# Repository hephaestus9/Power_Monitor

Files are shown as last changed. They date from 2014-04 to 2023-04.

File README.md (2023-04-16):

Power_Monitor
=============

Arduino and Processing sketches for Power Monitor Shield

*Boards v1r3 and v2r1 are not fully tested

This project is based on the work done by Christopher McNally.
Please view the Design_Report.pdf document for the write up of the project, and [website] (http://people.ece.cornell.edu/land/courses/eceprojectsland/STUDENTPROJ/2009to2010/csm44/index.html).

>The sample code was written for use with the 3000 Turn [CR Magnetics](http://www.crmagnetics.com/Products/CR3100-Series-P75.aspx) split core transformer. 

>If using the current transformer from [seeedstudio](http://www.seeedstudio.com/depot/Noninvasive-AC-Current-Sensor-100A-max-p-547.html?cPath=25_28) then the code needs to be changed, as this is a 2000 turn transformer.

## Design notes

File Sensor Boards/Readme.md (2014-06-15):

[Water Meter Board](http://www.instructables.com/id/Monitoring-residential-water-usage-by-reading-muni/)

[Voltage Sensor](https://courses.cit.cornell.edu/ee476/FinalProjects/s2008/cj72_xg37/cj72_xg37/index.html)

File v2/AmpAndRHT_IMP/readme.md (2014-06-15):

Electric Imp Code
=================

This code is exactly as it is running on v2r0 this is because of the Rx/Tx pins being switched on the arduino that I am using.  If you are breadboarding this then you can switch the pins to that stated in the comments of the device code.

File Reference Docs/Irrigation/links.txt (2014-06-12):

http://www.ianrpubs.unl.edu/pages/publicationD.jsp?publicationId=742
http://tlirr.com/products/pivot_management_options/
http://www.agsense.net/index.php  ~$1200 unit 200-300 monitoring fee

TDR
http://electronicdesign.com/displays/build-your-own-cable-radar

A time domain reflectometer (TDR) is a handy but rather expensive instrument, and isn�t commonly found on every bench. I used to rent them, but after having paid large bills for several years, I decided to make my own. I saved a bundle and was able to customize it for my needs.

A TDR performs a number of tasks, such as:

    sending a well-defined voltage pulse down the line and waiting for the echo.
    displaying the pulse and echo on a fast oscilloscope screen.
    measuring echo time to find cable length or distance to fault.

If you look at the list, you will find that a modern oscilloscope will do most of the job. The only thing needed for the TDR function is pulse generation. It turned out to be much easier to build than I had expected. A simple hex inverter in Advanced CMOS technology (74AC14) does the job admirably.

There are five basic design parameters that must be addressed: rise time, pulse width, amplitude, impedance, and PRF.

To be useful, the pulse should have a rise time that corresponds to the desired distance resolution. If you need 1-m resolution, then better than 10 ns is required. This design has a resolution better than 5 ns.

The pulse width can be quite short for short cables, but needs to be longer for greater length cables so that enough energy is introduced in the cable. If the energy is too low, there won�t be enough energy in the return wave to be detected reliably. This design allows a choice between 15 and 2500 ns. The 2500-ns pulse width will produce enough energy for a 5- to 10-km cable.

The other parameter that determines energy is amplitude. Too little amplitude won�t work in noisy installations. On the other hand, too much amplitude can be a problem if you�re working in installations with other cables that can pick up EMI and cause undesired responses in the system. Amplitudes between 1 and 10 V seem to serve most applications. This design uses 4 to 5 V as dictated by battery voltage.

Ordinary cables have impedances in the 50-300? range. Using a 250-? potentiometer (the low-inductance type) and a fixed generator impedance (50 ?), any impedance in that range can be achieved.

A 14-pin DIP, a handful of small components, a switch, and a potentiometer is all that�s needed. The 74AC family has quite hefty specifications. Among the features are 24-mA symmetrical sink/source current, and output impedance in the tens of ohms range. A 200-or 220-? resistor in series with each output will produce approximately a 250-? impedance. Paralleling five such circuits will give you close to 50-? impedance. And that�s about as low as you are likely to need. Most cables are in the 50- to 300-? range. Use the spare inverter for a simple, low duty-cycle RC relaxation oscillator and you have your pulse generator. The schematic shows the details (Fig. 1).

The power supply isn�t critical; I used three alkaline AA cells. Battery operation is very favorable�the batteries seem to last forever. If you use a battery-operated scope, like the THS 720 or 730, you will get better results than possible with an ac-powered instrument. The reason for this effect seems to be that some noise is introduced via the power-supply transformer capacitances. Construction is very straightforward. I used a ground plane and hook-up wire for my prototype. Later, I had a pc board made, and it works just as well. One factor must be kept in mind, though�good powersupply decoupling. I use a small (1 nF) ceramic disk and a 1-�F foil capacitor.

Figure 2 shows a 100-m cable with 500-? shunt resistance some 20 m from the start. The pulse that�s being sent down the cable starts at 40 ns.

In this case, the wave impedance of the cable is approximately 150 ?. The propagation speed is a little less than 200 m/�s. Because the wave has to travel both ways, the large echo at 5.5 divisions (1.1 �s) from the pulse�s front edge tells us where the cable ends. The fact that it goes positive tells us that the cable is open at the end.

The little echo observed 280 ns from the start is from a 500-? shunt resistor that should not have been there. The echo goes negative since this extra load lowers the impedance at this point.

Checking a LAN cable using this TDR is easy. By connecting to one end of the cable and looking at the echoes (there should be no echoes in a wellterminated cable), you can easily see if anything is wrong with the loading, terminators, or joints.

It�s just as easy to locate a fault in a buried cable using this TDR. Connect the TDR to one end of the cable and see if there�s any extra echo (going down if there�s an extra load or a short, going up if there�s a bad connection or an open cable). If one exists, you can be certain where the fault is located. The distance can be calculated from the delay (most cables have bidirectional wave speeds between 100 and 110 m/�s, so the calculation is very easy). By doing this, you will not need to dig an unecessarily long trench to repair the cable. You only dig where the fault is. The �cable radar� also is a great tool when checking antenna cables.

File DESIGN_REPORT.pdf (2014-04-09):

## ARDUINO BASED WIRELESS POWER METER

A Design Project Report

Presented to the Engineering Division of the Graduate School

of Cornell University

in Partial Fulfillment of the Requirements for the Degree of

Master of Engineering (Electrical)

By

Christopher McNally

Project Advisor: Bruce Land

Degree Date: May 2010

Abstract

Master of Electrical Engineering Program

Cornell University

Design Project Report

Project Title: Arduino based wireless power meter

Author: Christopher McNally

Abstract:

One avenue through which today’s energy problems can be addressed is through the reduction of energy usage in households. The existing utility system only provides feedback at the end of the month in the form of a bill and consumed kilowatt hours (kWh). A homeowner has no way to track their power usage on a more immediate basis.

The Arduino based wireless power meter is a non-invasive current meter for household power with a Matlab interface. Current is measured using split core current transformers. This data is then transmitted over a 802.11b connection through the home’s wireless router to the base station and Matlab interface. The project aims to provide a clear picture of a home’s current usage, and through this data provide an estimate to power consumption. The project also aims to identify which devices turn on and off by analysis of this current data. The goal of provided such data to a user is that they will optimize and reduce their power usage.

Report Approved by

Project Advisor:___________________________________________Date:________________________

Executive Summary

The Arduino based wireless power meter centered on the design and development of a current measurement device with an IEEE802.11b link to a base station running a graphical user interface (GUI). The project’s goal was to present a user with energy usage information in the hopes that they could use the information to optimize and reduce their energy consumption.

The system was comprised of the current transducers and their rectifier circuitry, the main Arduino board, the WiShield add-on board, and the base station computer. The software portion of the project resided on the Arduino board and on the base station computer. Current was measured from the two current carrying wires into the main power panel, sampled by the Arduino board, and then sent as a UDP packet over the Wi-Fi network to the base station computer. The base station’s software then parsed the packet, and converted the raw analog to digital conversion into current data, where it could be used to either display current usage to the user, or estimate apparent and real power for display to the user.

The project succeeded on most fronts. The update rate of data from the embedded side of the project to the base station was 20 Hz, with a measurement resolution of the RMS current of about 47.5 mA. This resolution allowed small changes in the current draw of the house to be visible while examining data. When compared to a consumer grade Wattmeter, the current measurement data showed an error of approximately 4.96% while measuring a purely resistive load consuming 180 W.

The wireless connection between the embedded electronics and base station was reliable for the networking equipment used. However, the 802.11b module used on the embedded side was not compatible with some wireless routers, meaning a user would have to change their router if they happened to be using an incompatible router. Range of the device seemed to be on par with most other 802.11b devices.

The feature of automatically detecting which devices turn on when based on the current data was not successful. Based on the data collected, the change in turn on current only differed significantly between devices by magnitude, not waveform. This meant the originally intended method of cross correlation between the incoming data and reference turn on data would not be effective. A method of identifying devices based on the magnitude of changes also proved to be unreliable. If more than one device powered on at once (such as a light switch turning on a room full of devices), the measurements would only see the net difference in current draw. This would lead to inaccuracies in device detection, and so the feature was dropped from the system.

## Table of Contents

## 1 Introduction

In the existing power utility set up, consumers are presented with usage information only once a month with their bill. The length of time between updates about power usage is far too long for a consumer to observe a changed behavior’s effect on power usage. In addition utility bills can be convoluted in how they present usage information, and a consumer may not be able to decipher changes in their power usage from the last bill. An opportunity to educate customers on power usage is lost because of these realities.

If a person can instantaneously see how much power leaving a device on by accident consumes per minute, they may be more careful in the future about letting devices run when not needed. The goal of creating more awareness about energy consumption would be optimization and reduction in energy usage by the user. This would reduce their energy costs, as well as conserve energy.

1.1 Household power

In most US households, power comes into the house through a three wire, split phase connection. Two “hot” wires carry current into the circuit breaker. A neutral wire also provides a connection to ground for the house circuit. Each hot wire has an RMS voltage of 120V +/- 5%. The wires are set up so that the AC waveforms are 180°, so that both lines combined can provide a 240V source for larger household appliances.

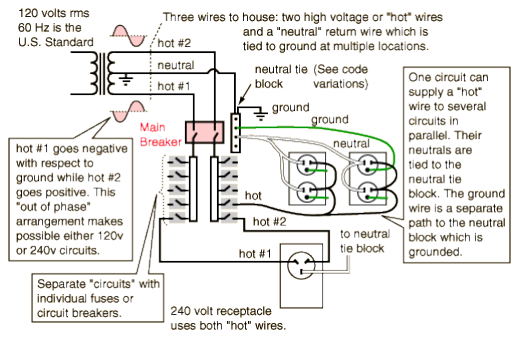
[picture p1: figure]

The apparent power consumed by a household can be found by taking the product of the RMS voltage and total RMS current. The real power can be calculated from discrete samples by taking the average of the product of the voltage and current samples over a specified window. Power factor can then be calculated by dividing real power by the apparent power. This project only included current measurements, and thus both power measurements are estimates, as opposed to measurements.

1.2 System requirements

The goals of the project were as follows:

- Accurately collect a house’s total current consumption safely, and with a relatively fast update rate.
- Transmit the information back to a base station to be represented visually to a user
- Identify when devices in the household turn on and off based on changes in the current data

Figure 1. US household three wire power connection [1]

To ensure the safety of the user and the ease of installation, a non-invasive method of measuring current was required. This meant that the current measurement circuit could not be in series with the mains power line, and could not require the disconnection of the line for any reason.

The wireless connection had to be able to integrate into the user’s home network, and comply with the IEEE802.11b standard. The data rate of the wireless connection also had to be sufficient to support the required update rate. The overall speed of both the wireless connection protocols had to be sufficiently fast that it would not interfere with obtaining the required amount of samples in a given period.

## 2 System design

### 2.1 Hardware

2.1.1 Overview

The hardware of the system consists of three parts: sensor capture, the MCU board, and the wireless board. The sensor capture hardware consists of the current transducers and rectifier circuit, connected to the analog to digital converter (ADC) of the MCU. The MCU board is a standalone Arduino Duemilanove development board. The wireless board is a shield designed to pair with the Duemilanove, created by AsyncLabs. A system overview can be seen in the appendix.

2.1.2 Arduino Duemilanove

The Duemilanove is a self contained USB development board centered on an ATMega328P. The operating voltage for most of the board is 5V, provided by an onboard voltage regulator. Power for the board can come from the USB connection, the 9V DC connection, or a battery connected to the V IN terminal. For this project, the 9V DC connection was used for power. A detailed schematic of the board can be found in the appendix.

The current measurement circuit connects to the Arduino
board through analog pins 0 and 1. This allows the Arduino to sample the output voltage from the current measurement circuit with the ATMega328’s 10-bit ADC. A voltage of 3.3V was applied from the USB to serial converter chip to the voltage reference pin, AREF, in order to provide the ADC with the required reference voltage. Connections to the ground and VCC pins were also provided for the op amp in the precision rectifier.

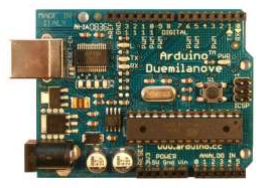
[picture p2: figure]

The USB connection on the board was used for programming
the chip and getting serial output for troubleshooting. The interface between USB and the ATMega328’s UART was provided by the Arduino’s built in USB to serial converter chip. The device showed up as a virtual COM port on the host PC, and could be interfaced with any program capable of reading and writing to a serial port.

Figure 2. Arduino Duemilanove board [2]

The board came pre-built from the distributor, so no major hardware assembly was required for use. Female headers are attached to each of the I/O and power ports, allowing wires to be inserted rather than soldered to each connection. The connections to the AREF pin, the analog pins, and the ground/VCC pins were all wired in this way. No major modifications of the stock hardware were required.

2.1.3 WiShield

The WiShield contains an 802.11b compliant wireless module that handles the network, data link, and physical layers of the design’s wireless connection. The board also includes required loading circuitry and a PCB antenna. A detailed schematic of the board can be found in the appendix.

The WiShield communicated with the Arduino main board through an SPI link and an interrupt line. The bi-directional SPI link allowed the Arduino to issue commands and send data to the 802.11b module, while the module could send received data back to the Arduino. The WiShield’s connections to the Arduino are detailed in Table 1.

Description | Arduino pin | ATMega328 pin
Slave select (SS) | 10 | PortB.2
Clock (SCK) | 13 | PortB.5
Master in, Slave out (MISO) | 12 | PortB.4
Master out, slave in (MOSI) | 11 | PortB.3
MCU interrupt | 2 | PortD.2
LED connection light | 9 | PortB.1

Table 1. WiShield connections to Arduino

The board came preassembled from AsyncLabs, thus no major hardware assembly was required for the wireless portion of the circuitry. Female headers with male leads underneath were included on the board, so that the WiShield was inserted into the Arduino main board’s female headers with no soldering required.

The system had known compatibility issues with some routers, as detailed on the AsyncLabs wiki page[3]. A Netgear WRN2000 was used as the router for this project because it was confirmed to be compatible by AsyncLabs. The router limitation was directly from limitations of the 802.11b module used, thus no software work around was attempted. For a production system this would represent a problem, but for a proof of concept system this was considered an acceptable limitation.

2.1.4 Current measurement

A split core current transducer was chosen as the current sensor
of the project because of its non-invasive nature. The sensor can be clamped onto the mains lines without interrupting power into the circuit breaker. Avoiding interrupting the lines into the circuit breaker makes the installation of the sensors both safer and easier. One sensor is clamped onto each “hot” wire going

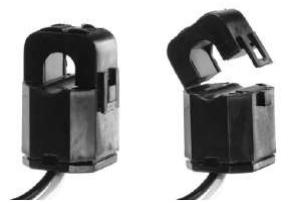
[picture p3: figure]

Figure 3. CR3110 current transducer [3]

into the circuit breaker. The total current being drawn by the household is the sum of the measured current in both wires.

The output of the current transducer is an AC voltage proportional to the AC current enclosed by the sensor’s ring. The amplitude of the voltage waveform is determined by this equation:

V =

I∗R
3100

Where V is RMS AC voltage across the burden resistor, I is the RMS AC current enclosed by the transducer, and R is the resistance of the burden resistor. This equation means that the output range of the sensor is determined by the selection of the burden resistance R. Selecting a higher burden resistance scales the output higher, providing a greater resolution of currents measurement. A higher resistance also means a smaller range of current measurement, and potentially damage to the MCU if the current is higher than intended for the design. When sizing the burden resistor, the range of linear behavior must also be taken into account. Figure 3 show the linear limit of the sensor with a dotted line. Measurements made beyond this limit will not follow the equation given above.

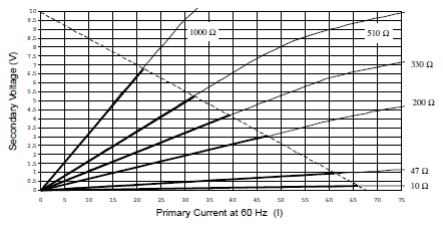
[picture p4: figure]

Figure 4. Voltage output from CR3110 [4]

The burden choice for this design rested on two points: maximum resolution given the available reference voltages on the Arduino, and selecting an appropriate range for measuring household current. A reference voltage of 3.3V was selected as the best option for the ADC, which meant that V MAX of the AC voltage signal had to be at or just below 3.3V. A burden resistance of 138.9 Ω would scale the output of the sensor to be 3.3V VMAX at the edge of the linear region, providing the largest range and resolution for the given reference voltage. A resistance of 150 Ω was used as an approximation due to the availability of resistors of that type. In this configuration, the maximum current that could be measured with the system was 48.2 A per line, giving a total range between both sensors of 96.4 A. For an apartment or small to medium household, this range worked well in testing. A larger range may be necessary for larger homes.

The VAC output of the sensor could not directly interface with the Arduino board because of the maximum limits of reverse voltage on the MCU pins. A rectifier was therefore required to ensure that a negative voltage would not be applied to the pins of the MCU. Two rectifier circuits were considered for this role: a full wave rectifier using a diode bridge, and a half wave precision rectifier an op amp. The diode bridge was also paired with a smoothing capacitor and discharging resistor in hopes of reducing the voltage ripple.

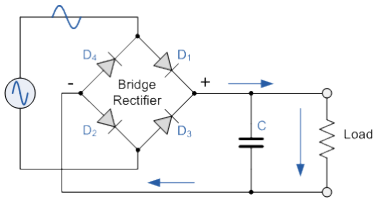
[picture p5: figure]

Figure 5. Full wave bridge rectifier with smoothing capacitor [5]

This design proved inadequate due to the forward voltage drop of the bridge rectifier and response to rapid changes in current. The forward voltage drop of the device used was around 1.1V, and depended on the current flowing through the device. A voltage drop this large essentially meant that currents below 1/3 of the maximum voltage would not be detected at all. In addition, accuracy of the voltage measurement was not certain due to the forward voltage drop changing with the amount of current going through the device. The smoothing capacitor also proved problematic because it either greatly reduced the response time of the circuit to rapid changes in the primary current, or let some of the AC waveform pass through to the ADC.

A precision rectifier is built around an op amp, two diodes, and two resistors. Using this circuit instead of the diode bridge solved the forward voltage drop problem, because the op amp corrects the output for any voltage loss over the two diodes. AC ripple was allowed to reach the analog pin and dealt with in software.

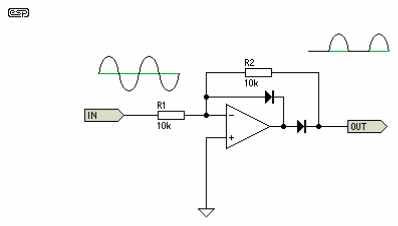
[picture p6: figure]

Figure 6. Precision rectifier [6]

### 2.2 Software

The software side of the system was split into the programs running on the Arduino and the GUI running on the base station. The Arduino was responsible for both capturing the output of both current sensors, and sending the measured data with timestamps over the wireless connection to the base station. The base station was responsible for reading the packets from the Arduino, converting the raw data into current/power information, and presenting it to the user in a clear fashion.

2.2.1 Arduino software

Data capture

Sampling of the voltage output of the current measurement circuit was done using the ADC on the ATMega328. The Arduino IDE included a family of functions for controlling and retrieving data from the ADC. The initial setup of the ADC was done using the analogReference(SOURCE) command, which set which reference voltage the ADC will use in its conversions. The external voltage reference option was set for this project in order to use a reference voltage of 3.3V. The function analogRead(port) returned a value between 0 and 1023, reflecting the level of voltage on the specified analog pin. AnalogRead() typically took around 100 µs to execute and return the conversion value.

As described in section 2.1.4, the smoothing of the half rectified voltage waveform was handled in software, as opposed to with a smoothing circuit or other filter. In each iteration of the main program, analogRead() was called 250 times, and the maximum value returned was saved. The voltage waveform had a period of about (1/60Hz), or 16.7 ms. Sampling 250 times typically took around 25ms, ensuring that at least a full cycle was sampled. Shorter times were experimented with, but sampling periods lower than this sometimes resulted in “dropped” measurements, where the maximum voltage seen was either during the zero portion of the period, or not near the maximum. The maximum value seen was reset when a packet was sent.

Time stamping was handled with the Arduino’s millis() function, which returned the number of milliseconds since power on or last reset. While not providing an absolute time of each measurement, the times stamps were useful in determining if packets were lost, and in graphing measurements more accurately in the time domain of the user interface. The time was taken to be at the beginning of each sampling period, so that measurements from both lines would be consistent with each other. Without this consistency, combining the waveforms on the base station side would be difficult.

WiFi connectivity and networking

The system uses WiShield’s open source implementation of µIP and a modified version of their example UDP communication app. µIP is an open source TCP/IP stack designed for embedded systems, with the ability to run a full TCP/IP stack on an 8 or 16 bit system with very limited RAM and instruction memory. A major reason the WiShield was selected over other 802.11 solutions for embedded systems was because µIP was already ported and released as open source code. This made prototyping of the system far faster and more focus on current and power measurement rather than networking protocols.

The WiShield’s core code contained all of the included functionality built in. In order to select a configuration, define statements in the header file “apps-conf” were uncommented. The UDP sending function of the system was based off the example UDP endpoint example, and thus the corresponding define statement was added to the configuration header. In addition, the configuration header for the µIP stack was altered to turn on UDP support.

The wireless connection set up was defined by a set of global variables at the beginning of the program and by AsyncLab’s function WiFi::init(). Parameters were recorded in these global variables at compile time and sent to the 802.11b module by init(). These parameters included the SSID, passphrase of the network, security type, IP of the WiShield and gateway, and subnet mask. The initialization of the connection was run during setup(), and blocked continuation of the program until a connection was established. The system was tested on a WPA2 encrypted network, thus the 802.11b module had to calculate the PSK from the passphrase given, adding substantial time (on the order of 30 seconds) to the set up phase of the program. Using an open or WEP encrypted network would eliminate this, but the added security of WPA2 was considered an acceptable trade off.

After setup, the handling of the wireless connection and data sending is handled by a call to WiFi::run() each iteration. This function calls the run process of µIP and checks to see if the send timer has expired. Data transmission is controlled by this send timer. When it expires, a call to udpapp_appcall(), and subsequently, handle_connection(), is made. In handle_connection() , the time stamp and both maximum ADC values are printed into a string buffer, which then gets passed to the µIP function uip_send(), which sends a UDP packet containing the passed data. The time out timer was set to be 50 ms, giving the embedded side a maximum update rate of 20 Hz. The packet structure is “timeData reading1 reading2”, with a space used as the delimiter between data values.

UDP packets were chosen over TCP/IP for several reasons. µIP’s implementation of TCP/IP had issues when working with any system that used delays acknowledgement packets (ACKs), because µIP only allows one packet to be in flight per TCP segment. This limitation can cause delays in transmits up to 500 ms, but typically about 200 ms [7]. A modification of the µIP stack that splits packets into two helps alleviate this issue, but the time required to work this modification into the AsyncLab implementation on the WiShield was not deemed worthwhile. Many of the features of TCP/IP were not critical to the project’s goals. The speed and simplicity of UDP was a better fit than the reliability of TCP/IP.

2.2.2 Base station interface

The base station ran as a Matlab figure, with each button having a call back function to execute on press. A screen shot of the interface can be found in the appendix. Each button or field in the interface is created with uicontrol and specifying the desired look and behaviors. The graph is created with a call to axes with the desired setup information. The start button begins the data collection routine, and continues until the stop button is pressed. Once the stop button is pressed, the collected data is saved to a MAT file of the time and date of the end of the data collection. The three ‘set’ buttons each set their respective parameters for the data collection function. The two drop down menus set the value to be graphed (current, estimated apparent power, or estimated real power) and which sensors to graph.

The data collection function operates as a loop, only breaking when the exit flag is set by the stop button, or an error occurs with the UDP feed. Before the loop is started, the UDP socket is opened and a timeout value is selected. The socket is opened and read from using Java functions imported into Matlab. The data returned by this method is a string of 8 bit unsigned integers reflecting the ASCII values of the characters in the data packet. Data is extracted from this format by first converting to a string, and then using sscanf to extract the three integer values.

After extracting the time and raw conversion data, they are each added to the array of data already collection. Time data is not further manipulated by the interface at this point. The ADC data is used to calculate the corresponding value of primary current measured using the equation:

Current =

ADC value ∗ VREF ∗ 3100
1023 ∗ 2 ∗ R

Where VREF is the reference voltage used by the ADC and R is the burden resistance of both sensors. After calculating this value, it is appended onto the existing current measurement array for each sensor.

Updating the graphs is also done by the data collection function. The program firsts checks to see whether the user has selected current, apparent power, or real power to be graphed. Based on this the current data is converted into the desired value, and then the last n samples are graphed. N is determined by the window size selected. A larger windows size shows a longer history of current data, but the ability to visually discern small changes in current decreases as the window size increases. Apparent power is calculated as

Papparent = IRMSVRMS

The RMS voltage is an estimate provided by the user, as the system right now does not have the capability of measuring the mains voltage. Real power is calculated as the apparent power times the power factor. Power factor was a user supplied estimate as well.

To create the effect of a sliding graph of the desired data, immediately before graphing the new data the axis was cleared of all items, including the axis labels and scaling. The data was then plotted, and labels assigned based on which data was being graphed. After calling the plot command and appropriate labeling commands, drawnow was called. This command flushes the graphics stack and forces Matlab to draw everything in the stack. Without this command Matlab would perform the default behavior of waiting to graph anything until the program exits.

## 3 Results

The system was successful in some respects, but did not meet all the design goals laid out during the project’s conception. The measurement resolution and update rate on the embedded side were both satisfactory for the goal of measuring energy usage, but the ability for the base station to detect different devices from turning on was not achieved, and the speed of execution of the base station software caused problems with receiving the UDP packets in a timely fashion.

The system was tested on a smaller scale than an entire household for accuracy due to a lack of tools available for verifying current flowing into the circuit breaker. A Kill-A-Watt™ was used to measure the current drawn by a household lamp. At the same time, the live wire of an extension cord was separated from the outer insulation and enclosed in one of the current transformers, allowing the system to measure current drawn by the lamp. Using this method, the system displayed an error of 4.96% from the output of the Kill-A-Watt™. The quantization error of the ADC was 4.75% at 1 A, and the two burden resistors had an error of 1.8% and 1.6%. The error displayed in this test can mostly be attributed to these factors. When measuring higher currents, the quantization error would decrease linearly, meaning measuring larger currents would be more accurate. The error rate observed here can be thought of as a worst case scenario in this regard, with a lower error rate during normal operation.

A 20 minute test of measuring current through the main breaker yielded the results in figure 7. Figure 7b is the observed current in both sensors. The large initial spike in voltage is possibly an artifact from the current transducer itself reacting to power on. The large changes in current were attributed to the electric oven which was on during the testing. The next smallest change in current is thought to be a refrigerator, but is not known for certain.

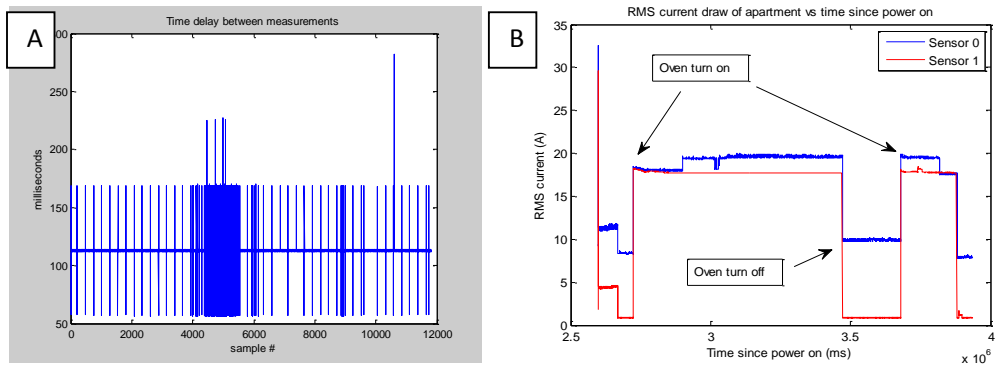
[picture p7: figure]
Time delay between measurements; sample # milliseconds; Time since power on (ms); RMS current (A); Sensor 0; Sensor 1 Oven turn on; Oven turn off

Figure 7a is a plot of the time difference between the time stamps of the samples. On average this time difference was 113 ms, with a maximum delay of 282 ms and a minimum of 56 ms. The average time difference was about twice the theoretical maximum based on the transmission timer set in the embedded code. This test suggests that the average update rate of the system was about 8.8Hz. A potential source of slowdown could be extra overhead from the µIP stack that was unforeseen during development. This possibility was ruled out by verifiying the timing of packets by monitoring the network with Wireshark.

Section of code | Min time(ms) | Max Time(ms) | Average (ms)
Overall | 47.4 | 238.2 | 112.8
Plotting and graphics | 36.4 | 118.9 | 44.7
UDP receiver | .310 | 176.5 | 67.8
All else | .169 | 5 | .269

Table 2. Statistics of time of execution data

RMS current draw of apartment vs time since power on

Figure 7. 20 minute system test

The MATLAB commands tic and toc allow routines to be timed. Three separate instances of this timer were added to the base station software to gain insight into the dropped packet problem. The results of this test can be seen in figure 8a, along with the averages for each portion in table 2. The data observed suggests that the timing problem is a combination of the Java UDP receiver code and plotting code taking too long to execute, and therefore causing packets to be missed. A modified plotting section made use of the set command in Matlab by changing the values stored in the data fields for the lineobject created by the initial plot command. The test results with this configuration can be seen in figure 8b. The execution time of the plot section was significantly reduced, with a new average execution time of 16.5 ms. Unfortunately this performance increase does not solve the problem of lost packets, because the receiver function is still sufficiently long in execution time that packets would still be missed. The next version of the system should employ changing the line object each iteration over using the plot command, but will also need to find a new implementation of a UDP receiver to achieve

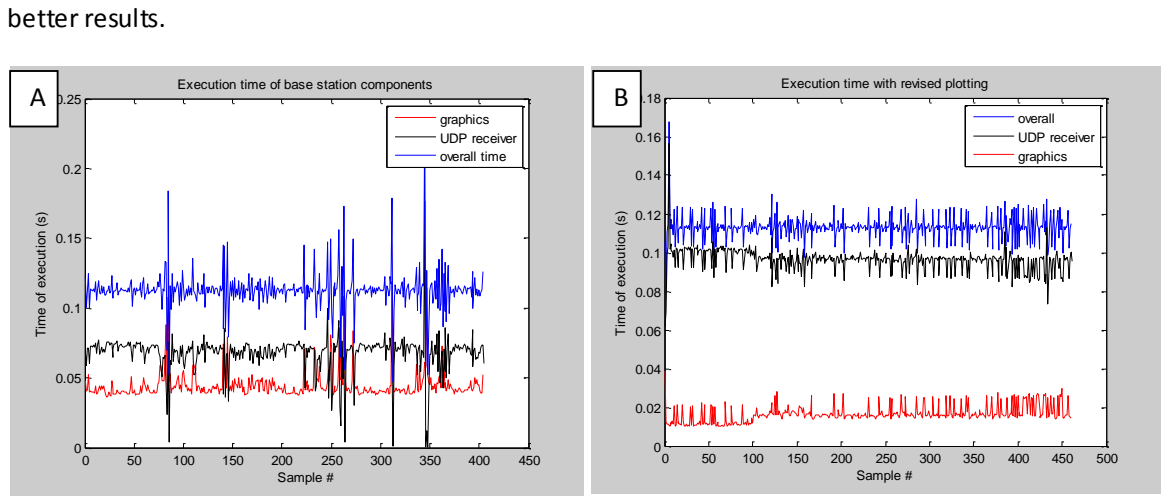
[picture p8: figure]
better results.; Sample #; Time of execution (s); graphics; UDP receiver overall time; Execution time with revised plotting; overall; UDP receiver graphics

Fig 8. Execution time of base station subroutines

Accuracy of the power estimates depended on the user supplied power factor and RMS voltage. When values were taken from a Kill-A-Watt™, the error was the same as a current only measurement. Unfortunately this method could not be applied when measuring the lines into the circuit breaker, at least for power factor. The addition of a voltage measurement component to the project would add the ability to more accurately estimate both apparent power and real power. The complexity and cost of the system would increase, but the ability to more accurately show user real power data would be valuable. The downside would be that a high voltage interface would be required in order to measure the voltage, increasing the safety risk of installation.

## 4 Conclusion

The system was successful in measuring current within an acceptable range of error, and sending that information at a higher update rate than previous similar projects have done. Moving time expensive floating point calculations off the Arduino and performing them on the base station helped to speed up

Execution time of base station components execution time, but difficulties with plotting data and receiving the packets on the base station side lowered performance.

The device detection feature may still be realized if the update rate could be recovered from the lost packet issue, but more likely a more detailed analysis of the shape of the waveform would be needed to do such turn on and turn off detection. Parameters like harmonics and distortion of the waveform for both current and voltage would be useful in identifying which devices are running.

The project was a valuable experience in the design, implementation, and testing of a system that involved several discrete hardware and software components. The use of an open source project for such a central function as the IP stack in the project was initially planned to be a large drain in design time, but ended up greatly accelerating the design of the wireless part of the embedded system. More time was available for the current measurement circuit, which was able to go through several designs before an acceptable one was reached.

Ultimately the system accomplished its primary goal of presenting energy information to a user in a clear way. An individual could watch the interface and visibly see the effect of leaving an appliance or device on, or see the difference in remembering to turn the lights off when they are not needed. More functionality in this regard would have been helpful, specifically long term averages and either numerical or visual comparisons between older data and present data.

## 5 Appendix

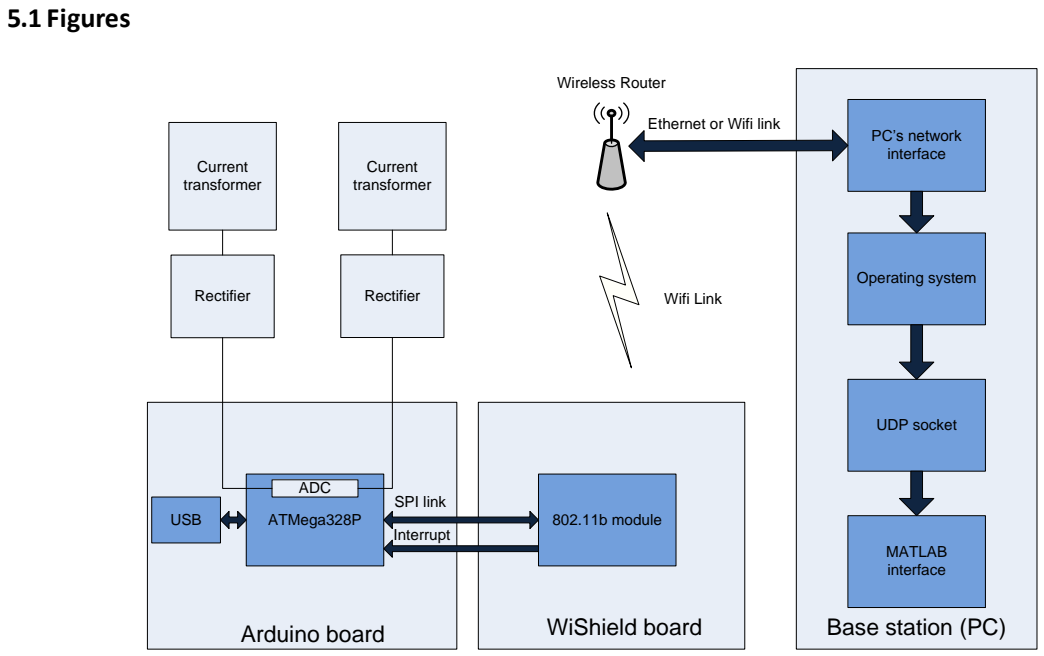
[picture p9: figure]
5.1 Figures; Current transformer; Current transformer Rectifier; Rectifier; Arduino board USB; ATMega328P ADC; Wifi Link; Wireless Router; PC’s network interface; Operating system; UDP socket; MATLAB interface Base station (PC); Ethernet or Wifi link

WiShield board ⁸⁰².11b module SPI link Interrupt

Figure 9. System diagram

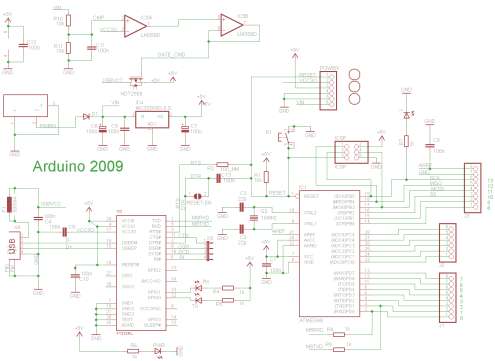
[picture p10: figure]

Figure 10. Arduino board schematic [8]

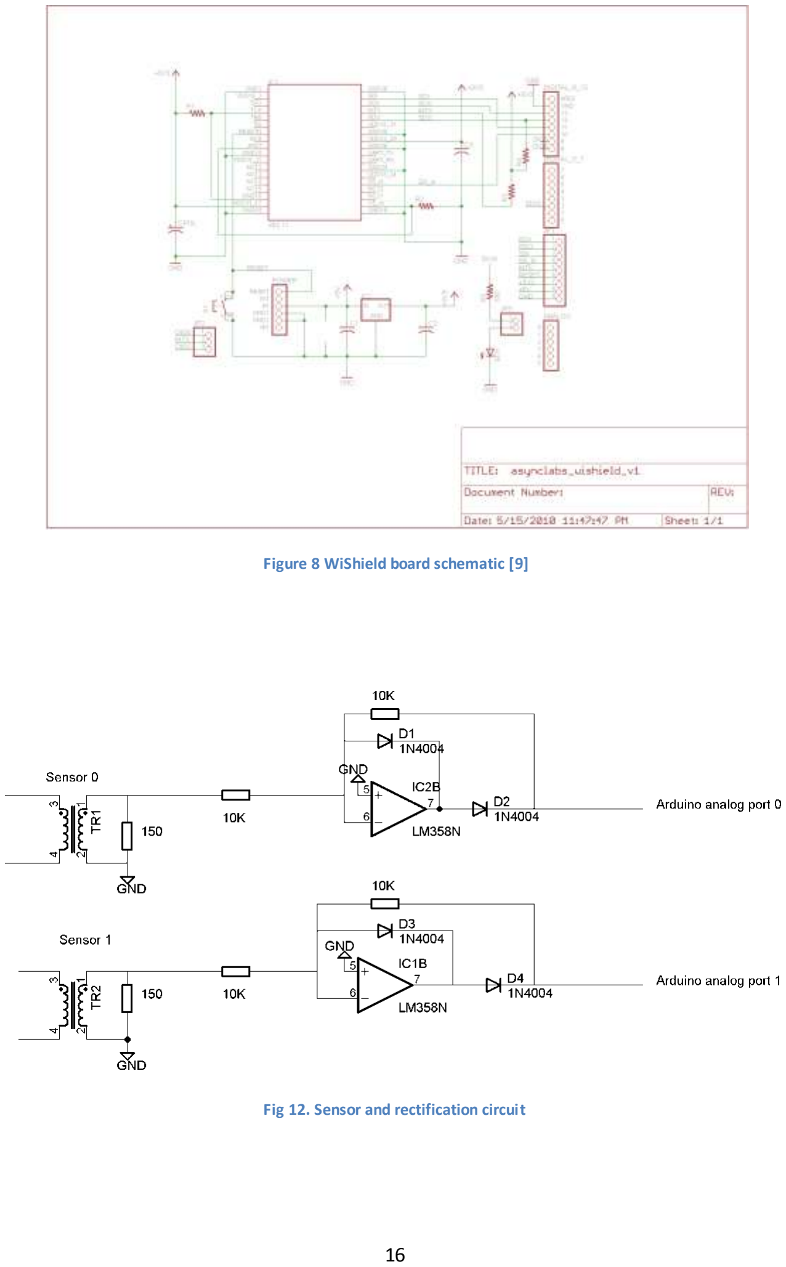
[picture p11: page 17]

Figure 8 WiShield board schematic [9]

Fig 12. Sensor and rectification circuit

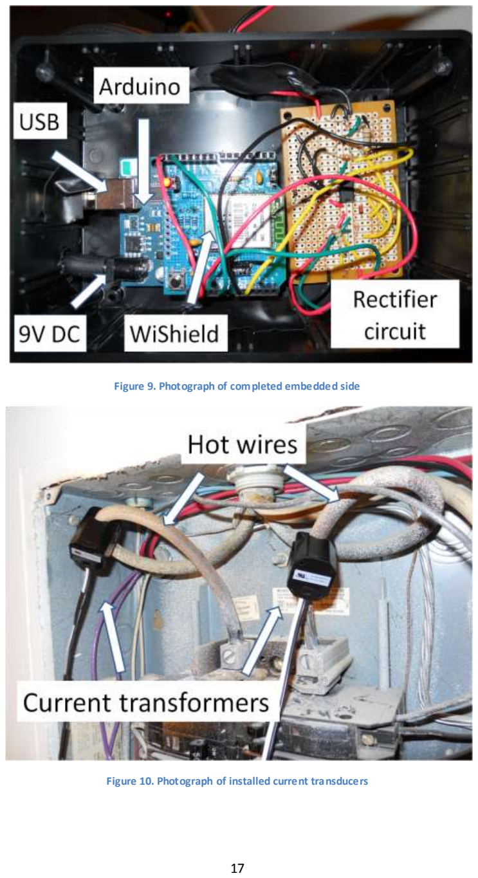
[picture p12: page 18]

Figure 9. Photograph of completed embedded side

Figure 10. Photograph of installed current transducers

Figure 11. Matlab base station interface

### 5.2 Code

5.2.1 Arduino main file

/*
* Modified_UDPApp
* Reads analog ports 0 and 1, and sends a UDP packet with their value * Based on UDP endpoint app provided by AsyncLabs
*
* Written by Chris McNally - csm44@cornell.edu
* Cornell University
*
*
*
* Version History :
* Version | Author Date | Comments
* 1.0 | CM | ? | Modified UDP endpoint example code to send packet at regular invervals.
* 1.1 | CM | ? | Added analog read portion,
* 2.0 | CM | 4/26/10 | Added time stamping, sending time and ADC readings in packet. Also
added max reading
*/

#include <WiShield.h>

0 | 0.1 | 0.2 | 0.3 | 0.4 | 0.5 | 0.6 | 0.7 | 0.8 | 0.9 | 1

0

0.2

0.4

0.6

0.8

1

Collected Data

#define WIRELESS_MODE_INFRA | 1

#define WIRELESS_MODE_ADHOC | 2

// Wireless configuration parameters ----------------------------------------
unsigned char local_ip[] = {192,168,1,100}; | // IP address of WiShield
unsigned char gateway_ip[] = {192,168,1,1}; | // router or gateway IP address
unsigned char subnet_mask[] = {255,255,255,0};// subnet mask for the local network
const prog_char ssid[] PROGMEM = {"o_o"}; | // max 32 bytes
unsigned char security_type = 3; | // 0 - open; 1 - WEP; 2 - WPA; 3 - WPA2

// WPA/WPA2 passphrase
const prog_char security_passphrase[] PROGMEM = {"dvor@k123"}; // max 64 characters

// setup the wireless mode
// infrastructure - connect to AP
// adhoc - connect to another WiFi device
unsigned char wireless_mode = WIRELESS_MODE_INFRA;

unsigned char ssid_len;
unsigned char security_passphrase_len; //---------------------------------------------------------------------------int maxReading1 = 0;
int maxReading2 = 0;
int tempReading1 = 0;
int tempReading2 = 0;
long readingTime1 = 0;
int packetSent = 0;
//long readingTime2 = 0;
//long tempTime = 0;

void setup()
{
WiFi.init();
//Serial.begin(9600);
}

void loop()
{
//if we are on a new packet, assign a new time value if(packetSent)

{
readingTime1 = millis();
//Serial.println(maxReading1); packetSent = 0;
maxReading1 = 0;
maxReading2 = 0;
}
int i;
//Run for 20 samples to capture peak of voltage signal for(i=0;i<250;i++)
{
//Get ADC reading for both sensors
tempReading1 = analogRead(0);
tempReading2 = analogRead(1);
//if either reading larger than max value seen since //last transmission, set as new max value and record //time
if(tempReading1 > maxReading1){
maxReading1 = tempReading1;
}
if(tempReading2 > maxReading2){ maxReading2 = tempReading2; }
}
//run wifi routine
WiFi.run();
}
5.2.2 UDP.c

#include "uip.h"

#include <string.h>

#include "udpapp.h"

#include "config.h"

#define STATE_INIT | 0

#define STATE_LISTENING | 1

#define STATE_HELLO_RECEIVED | 2

#define STATE_NAME_RECEIVED | 3

//ADC measurements (range 0-1023)
extern int maxReading1;

extern int maxReading2;
extern long readingTime1;
//extern long readingTime2; extern int packetSent;

static struct udpapp_state s;

void dummy_app_appcall(void) {
}

void udpapp_init(void)
{
uip_ipaddr_t addr;
struct uip_udp_conn *c;
//IP address to send packets to uip_ipaddr(&addr, 192,168,1,2);
//create UDP connection to address at port given c = uip_udp_new(&addr, HTONS(12344)); if(c != NULL) {
uip_udp_bind(c, HTONS(12344)); }
s.state = STATE_INIT;
PT_INIT(&s.pt);
}

static PT_THREAD(handle_connection(void)) {
//mark beginning of protothreat PT_BEGIN(&s.pt);
//translate data into string
char data[100];
sprintf(data,"%lu %u %u",readingTime1,maxReading1,maxReading2); //give string over to uIP, send packet
uip_send(data,strlen(data));
//reset max readings for next sampling period
packetSent = 1;
//mark end of protothread
PT_END(&s.pt);
}

void udpapp_appcall(void)

{
handle_connection();
}
5.2.3 Matlab interface

function PowerMeter
%Powermeter - GUI interface for Wireless Power Meter project
%Created by Chris McNally - csm44
%Cornell University
%%%%%%%%%%%%%%%%%%%%%%%%%%%Revision history%%%%%%%%%%%%%%%%%%%%%%%%%%%%%%
% Date | Version | Notes
% 4-13-10 | 1.0 | Initial version
% 5-11-10 | 2.0 | Update graphical elements and new data packet
format
% 5-13-10 | 2.1 | Changed graph axis to look better, added sensor
selector

%declare main figure window at position 300,300
%800x600 windows
meter = figure('Position',[ 5 5 1000 600]);

%%%%%%%%%%%%%%%%%%%%%%%%%%%%layout parameters%%%%%%%%%%%%%%%%%%%%%%%%%%%%% %Graph
%powerGraphPos1 = [70 20 400 200];
powerGraphPos2 = [70 40 850 260];
%powerGraphPos3 = [70 560 400 200];

%%%%%%%%%Parameters%%%%%%%%%%%% %reference voltage on arduino
vRef = 3.3;
%Burden resistance
bR = 150;
%Estimated power factor
pFactor = .7;
%Estimated mains voltage
Vrms = 121;
%#of samples to display on graph windowSize = 100;
samplesCollected = 0;
%stop flag
keepTruckin = 1;
%1 = Current
%2 = Apparent power
%3 = Real power
whatToGraph = 1;
offset = 450;
%current data
timeData1 = [];
currentData1 = [];
%timeData2 = [];
currentData2 = [];
avg = '';

graphData = [];
graphTime = [];

%%%%%%%%Button positions%%%%%%%%% startButtonPos = [660-offset 560 60 30]; stopButtonPos = [760-offset 560 60 30]; setRPos = [790-offset 500+20 60 20]; setVrefPos = [790-offset 450+20 60 20]; setPfPos = [790-offset 400+20 60 20];

%%%%Parameter UI positions%%%%% rTextBoxPos = [690-offset 500+20 60 20]; rLabel = [540-offset 500+20 100 20]; vRefTextBoxPos = [690-offset 450+20 60 20]; vRefLabel = [540-offset 450+20 100 20]; pfTextBoxPos = [690-offset 400+20 60 20]; pfLabel = [540-offset 400+20 100 20]; avgTextBoxPos = [];
avgLabel = [];
graphSelectPos = [690-offset 350+20 100 20]; graphSelectLabelPos = [540-offset 350+20 100 20];
sensorSelectPos = [690-offset 300+20 100 20];
sensorSelectLabelPos = [540-offset 300+20 100 20]; %%%%%%%%%%%%%%%%%%%%%%%%%%%Object declarations%%%%%%%%%%%%%%%%%%%%%%%%%%%% %%%%%%%Graphs%%%%%%%%%
%powerGraph1 =
axes('Parent',meter,'Units','pixels','Position',powerGraphPos1); %title('Sensor 1');
powerGraph2 =
axes('Parent',meter,'Units','pixels','Position',powerGraphPos2); title('Collected Data');
%powerGraph3 =
axes('Parent',meter,'Units','pixels','Position',powerGraphPos3); %title('Total');

%%%%%%%%%%Buttons%%%%%%%%%%%
startButton = uicontrol(meter,'Position',startButtonPos,... 'String','Start',...
'Callback',@collectData);
stopButton = uicontrol(meter,'Position',stopButtonPos,... 'String','Stop',...
'Callback',@stopCollectData);

setRButton = uicontrol(meter,'Position',setRPos,... 'String','Set',...
'Callback',@setR);

setVButton = uicontrol(meter,'Position',setVrefPos,... 'String','Set',...
'Callback',@setV);

setPFButton = uicontrol(meter,'Position',setPfPos,... 'String','Set',...
'Callback',@setPF);
%%%%%%%%Text fields%%%%%%%%
%%%User definable%%%%
burdenLabel = uicontrol(meter,'Style','text',... 'String','Burden (Ohms)',...

'Position',rLabel);

burdenR = uicontrol(meter,'Style','edit',... 'String','150',...
'Max',1,'Min',0,...
'Position',rTextBoxPos);

voltageLabel = uicontrol(meter,'Style','text',... 'String','Vref (V)',...
'Position',vRefLabel);

voltageReference = uicontrol(meter,'Style','edit',... 'String','3.3',...
'Max',1,'Min',0,...
'Position',vRefTextBoxPos);

pfLabel = uicontrol(meter,'Style','text',... 'String','Est power factor',... 'Position',pfLabel);

powerFactor = uicontrol(meter,'Style','edit',... 'String','.7',...
'Max',1,'Min',0,...
'Position',pfTextBoxPos);

graphSelectLabel = uicontrol(meter,'Style','text',... 'String','Graph value',... 'Position',graphSelectLabelPos);

graphSelect = uicontrol(meter,'Style','popupmenu',... 'String',{'Current','Est App Pow','Est Real Pow'},... 'Value',1,'Position',graphSelectPos);

sensorSelectLabel = uicontrol(meter,'Style','text',... 'String','Sensor Options',... 'Position',sensorSelectLabelPos);

sensorSelect = uicontrol(meter,'Style','popupmenu',... 'String',{'Sensor 0+1','Sensor 0','Sensor 1'},... 'Value',1,'Position',sensorSelectPos); %%%Outputs%%%

%%%%%%%%%%%%%%%%%%%%%%%%%%%%%%Functions%%%%%%%%%%%%%%%%%%%%%%%%%%%%%%%%%%% %receives UDP packets from Arduino
% | %function data = receiveData()
%
% | end
%
% | %grabs new data and graphs data
% | function updateGraph()
%
% | end

%loops, checks whether to collect data or not function collectData(hObject,eventdata) keepTruckin = 1;
%grab new packet
import java.io.*
import java.net.DatagramSocket
import java.net.DatagramPacket
import java.net.InetAddress
%receieve port, set on Arduino. Default is 12344. port = 12344;
socket = DatagramSocket(port);
%timeout if no packets are received (milliseconds) timeout = 1000;
%estimated length of incoming packet
packetLength = 100;
socket.setSoTimeout(timeout); while(keepTruckin)
try
%grab the packet
packet =
DatagramPacket(zeros(1,packetLength,'int8'),packetLength); %close socket
socket.receive(packet);
%extract data from packet
mssg = packet.getData;
mssg = mssg(1:packet.getLength);
newData = mssg;
catch receiveError
% Determine whether error occurred because of a timeout. if
~isempty(strfind(receiveError.message,'java.net.SocketTimeoutException')) errorStr = sprintf('Failed to receive UDP packet; connection timed out.\n');
else
errorStr = sprintf('Failed to receive UDP packet.\nJava error message follows:\n%s',receiveError.message); end % if
try
socket.close;
end % try
error(errorStr);
end % try
%sort new data
parsedNewData = cellstr(char(newData')); parsedNewData = parsedNewData{1}; parsedNewData = sscanf(parsedNewData,'%d');
%add new power data to data set
timeData1 = [timeData1 ; parsedNewData(1)]; currentData1 = [currentData1 ; parsedNewData(2) ./ (1023.*sqrt(2)*bR) .* vRef .* 3100]; %timeData2 = [timeData2 ; parsedNewData(3)]; currentData2 = [currentData2 ; parsedNewData(3) ./ (1023.*sqrt(2)*bR) .* vRef .* 3100]; whatToGraph = get(graphSelect,'Value');
switch whatToGraph
%%%%%%%%%Graphing current data%%%%%%%% case 1

%samplesCollected = samplesCollected + 1; if(windowSize > samplesCollected)
graphData = currentData1 + currentData2; graphTime = timeData1;
else
graphData = currentData1(samplesCollected+1-windowSize:end) + ...
currentData2(samplesCollected+1-windowSize:end); graphTime = timeData1(samplesCollected+1-windowSize:end);
end
yString = 'RMS current (amps)';
xMax = 80;
%%%%%Graphing apparent power%%%%%%%% case 2
%Apparent power = Vrms * Irms if(windowSize > samplesCollected)
graphData = (currentData1 + currentData2) .* Vrms; graphTime = timeData1;
else
graphData = (currentData1(samplesCollected+1-windowSize:end,:) + ...
currentData2(samplesCollected+1-windowSize:end,:)) .* Vrms; graphTime = timeData1(samplesCollected+1-windowSize:end);
end
yString = 'Apparent power (VA)';
xMax = max(graphData);
%%%%%%graphing real power%%%%%%%
case 3
%Real power = Apparent power * power factor if(windowSize > samplesCollected)
graphData = (currentData1 + currentData2) .* Vrms .*pFactor;
graphTime = timeData1;
else
graphData = (currentData1(samplesCollected+1-windowSize:end,:) + ...
currentData2(samplesCollected+1-windowSize:end,:)).* Vrms .*pFactor;
graphTime = timeData1(samplesCollected+1-windowSize:end);
end
yString = 'Real power (W)';
xMax = max(graphData);
end
samplesCollected = samplesCollected + 1; cla;
plot(powerGraph2,graphTime,graphData); title('Collected Data');
xlabel('time from power up (ms)');
ylabel(yString);
axis(powerGraph2,[min(graphTime) max(graphTime)+1 0 xMax+1]); axis manual;
drawnow;
end

socket.close;
end

%sets stop flag
function stopCollectData(hObject,eventdata) %grab current time
c = datestr(now, 'mmm dd, yyyy HH MM SS'); %save workspace
save(c);
keepTruckin = 0;
samplesCollected = 0;
currentData1 = [];
currentData2 = [];
timeData1 = [];
graphData = [];
graphTime = [];
cla;
end

function setR(hObject,eventdata)
bR = str2num(get(burdenR,'String')); end

function setV(hObject,eventdata)
vRef = str2num(get(voltageReference,'String')); end

function setPF(hObject,eventdata)
pFactor = str2num(get(powerFactor,'String')); end

end

## References

[1] R. Nave. Household Wiring. http://hyperphysics.phy-astr.gsu.edu/HBASE/electric/hsehld.html , 1999
[2] Arduino. http://arduino.cc/en/Main/ArduinoBoardDuemilanove. 2009
[3] CR Magnetics. CR-3110 data sheet. http://www.crmagnetics.com/products/Assets/ProductPDFs/CR3100.pdf. 2010.
[4] CR Magnetics. CR-3110 data sheet. http://www.crmagnetics.com/products/Assets/ProductPDFs/CR3100.pdf. 2010.
[5] Wayne Storr. Full-wave Rectifiers. http://www.electronics-tutorials.ws/diode/diode_6.html. 2010
[6] Rod Elliot. Precision Rectifiers. http://sound.westhost.com/appnotes/an001.htm. 2009.
[7] Adam Dunkels. http://www.sics.se/~adam/uip/uip-1.0-refman/.
[8] Arduino Duemilanove. http://arduino.cc/en/Main/ArduinoBoardDuemilanove. 2009
[9] AsyncLabs. http://asynclabs.com/wiki/index.php?title=WiShield_1.0 2009

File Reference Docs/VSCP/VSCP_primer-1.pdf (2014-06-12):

## VSCP Primer

VSCP stands for 'very simple control protocol', it is an automation protocol suitable for all sorts of automation jobs among which home-automation. In a VSCP network a common physical layer (wired bus, radio link, ...) connects the individual nodes to form the automation network. This network is a distributed system with all nodes working autonomous. On the bus there can be nodes reading switches, there can be nodes
controlling lamps, nodes that read temperature, | How they communicate & how this
results in an automation function is detailed in the next chapters.
VSCP is independent from the physical layer (bus) used. There is a subset of the protocol (level I) that is very much tailored to the CAN bus. There is also a version of the protocol intended for Ethernet, one for TCP and also a wireless version of the protocol. All share the same common message fields & framework.

Event based
VSCP works based on 'events'.
Each time an ‘event’ occurs this event is broadcasted towards all other nodes. Each node on the network will receive the event and will decide if this event needs to be handled or
not. The example on the right
shows a button being pressed.

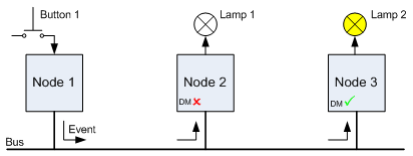
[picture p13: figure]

This will result in node 1 sending an event message onto the bus informing all others the button is pressed. Node 2 receives the message but decides this button should not trigger an event for node 2. Node 3 receives the message and decides this button should trigger Lamp 2 to turn on.
There can be ‘events’ for all sorts of things happening: it can be a button pressed, presence
sensor being triggered, sun setting, | Events can also be send periodically, for instance a
temperature reading every minute. VSCP pre-defines a whole plethora of events that could be happening. These events are defined into classes & types. Whether or not an event received should be handled is determined by the ‘decision matrix’ or DM in short. Also the DM is explained further.

Event Class & Type
Events are organized into ‘Classes’. A class is a collection of events that somehow belong together. There are classes for ‘ALARM’, ’MEASUREMENTS’, ’CONTROL’, ’INFORMATION’, etc. Currently VSCP specifies about 25 classes, but has room for many more ¹
Each class is on its turn subdivided into ‘types’. A type further specifies the event within the class. For instance, events of Class ‘20’ (0x14) are ‘INFORMATION’ events. In this class there is a subtype ‘1’ (0x01) ‘BUTTON’ signaling a button being pressed. In this same
INFORMATION class there are also types to signal ‘ON’, ‘OFF’, ‘BELOW LIMIT’, etc. Likewise in class ‘measurements’ there are types to signal temperature, current, voltage, etc.
Having all these classes & types defined makes the nodes speak the same language. Perhaps some definitions make you wonder what you will ever use them for but it’s nice they are there. For a full list of pre-defines classes & types check the VSCP wiki.

1
VSCP Level II has a 16bit CLASS field allowing up to 65536 classes to be defined. Also the TYPE field is 16bit, allowing 65536 types to exist within each class.

Example 1

by kurt.sidekick@yahoo.com

VSCP event datagram structure
Events that are broadcasted contain a number of fields together forming one VSCP datagram. Exactly how these fields are mapped onto the physical layer is specified for a
number of physical layer protocols such as CAN, Ethernet, TCP, | For others it is not yet
defined but it is in general not difficult to map these fields onto a physical layer protocol.

There are 2 ‘levels’ of the VSCP protocol called ‘LEVEL I’ & ‘LEVEL II’. They are both basically the same protocol but differ in size of the different fields. Level II is intended to be run on nodes that have little resource constraints and can easily cope with larger message sizes. Level I is intended to run on nodes with more constrained resources and fields are defined a bit more conservative. Level I is in fact a subset of level II and with an appropriate gateway events can transverse between a Level I & II network.

An exact description of Level I / II fields can be found in the wiki.

ITU

CRC
0to512bytes

DataPayload
16bits

DataSize
16Bytes

senderGUID
16bits

TYPE
16bits

CLASS
1bit

IDHardcoded
3bits

Priority

Table 1: VSCP datagram (level II)

15 bits

CRC
0to8bytes

DataPayload
4bits

DataSize
1Byte

senderNickID
8bits

TYPE
9bits

CLASS
1bit

IDHardcoded
3bits

Priority

Table 2: VSCP datagram (level I)

Decision Matrix
When events are received by a node the node needs to determine if it needs to execute a task based on that event. This is done by evaluating the ‘decision matrix’ or DM in short. The DM matrix is made of a number of IF … THEN … conditions. Each such IF/THEN condition is called a ‘line’ and multiple lines make up the decision matrix.

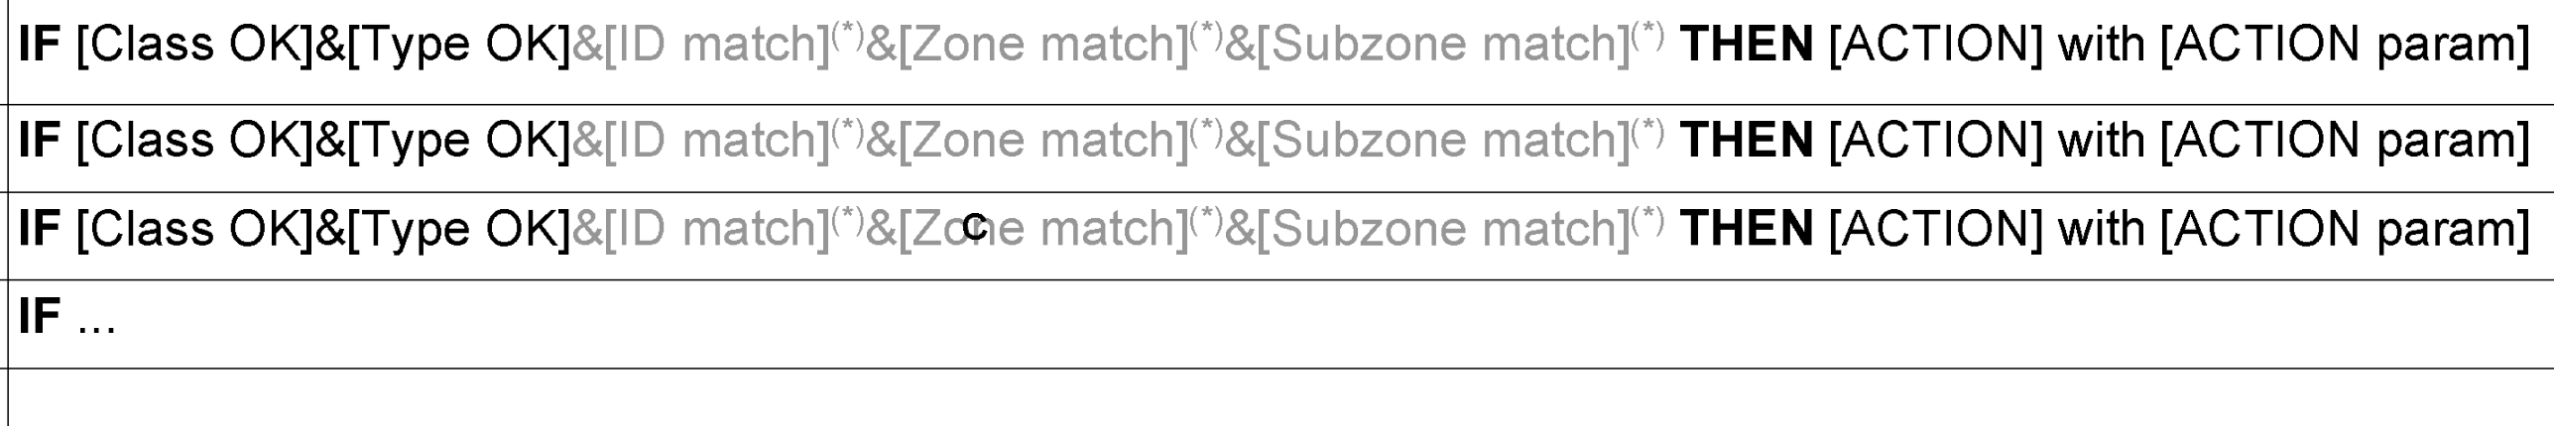
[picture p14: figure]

Figure 1: Decision Matrix

The Class & Type of the incoming message is always evaluated by a DM line. Evaluating Class & Type is done by passing the Class/Type thru a mask first & then comparing with a filter. This method allows multiple class/Types to trigger a valid condition for 1 line of the DM. The other conditions for the DM line (SenderGUID, Zone, Subzone) are optionally evaluated.

If the DM line is valid then the ‘ACTION’ is executed. Together with the ‘ACTION’ there is an ‘ACTION parameters’. An example ACTION would be: ‘turn-on relay 6’ with ‘6’ being the ‘action parameter’.

Figure 2: Class/Event mask & filter

Exactly which ACTIONs are possible by the receiving node is determined by the design of the node itself. It is up to the firmware developer to define which actions can be executed. By then documenting the possible action in the MDF file (see later) the configuration SW will know how to select this action.

The DM can be modified by setting the appropriate node configuration registers. A convenient way to do this is using the VSCPWorks configuration SW.

DataPayload
An event being send can also carry a data payload. The content & organization of this payload is depending on the class & type of the event. For example an event of class ‘10’ (measurement) and type ‘6’ (temperature) is will carry the temperature data (with coding determined by byte 0, degrees or celsius) in it’s payload. A ‘button’ event will carry information about the button & button zone/subzone in it’s datapayload. For each class/type the data formatting is determined in the spec, please consult the wiki for details.

Zone / Subzone
Some (quite some) events contain a field ‘zone’ and a field ‘subzone’ in their datapayload. This functionality is present to make ‘grouping’ of nodes possible.
For instance we could determine that all buttons controlling a certain lamp are part of the same group. This simplifies the DM for certain scenarios. Instead of having one DM line a the lamp node for each button (1 line per button: IF button x then turn-on lamp) we could have

### 1 DM line only saying ‘IF (zone match) THEN turn-on lamp’. Making multiple node switches

part of a group is done by configuring the nodes, the firmware of the node will support this functionality. How this is done is explained in the section about ‘register layout’ & ‘MDF’.

Putting it all together.
We’ve now covered the basic components of VSCP to make an automation function work. Taking once more example 1 we now know the node will send an event of class ‘20’ (information) of type ‘1’ (button). Since the button was configured to belong to subzone 2 the datapayload of the event will contain ‘subzone = 2’ information.
Both node 2 & node 3 will have an identical DM line. Their DM lines will read ‘IF (class=20) & (type=1) & (subzone=match) THEN turn-on lamp’. However, node 2 will be configured to belong (for instance) to subzone 1 and node 3 will belong to subzone 2. The incoming message will not result in a valid DM condition for node 2 since the subzone of the message does not match that of node 2. The incoming message will result in valid DM condition for node 3 since the subzones match. Node 3 will then execute his action: turning on the lamp.

Configuring a VSCP node
A node needs to be configured appropriately before it will execute its function. Each VSCP node provides its own set of configuration registers tailored for its function. A button node would have some possibility to configure the zone/subzones the buttons belong to. A temperature node would have some possibility to set trigger values. Also configuring the DM is part of configuring a node.

Configuration registers
Configuring a node is done by writing to
‘registers’. Each (Level I) node provides access to
256 registers. The highest 128 registers are
reserved for VSCP core functions. In these 128 registers we find items such as node GUID, Nickname, MDF and a paging register. The lower 128 registers are free for application specific use. If 128 registers are not sufficient then there is a 16bit paging possibility. This allows for 65536 x 128 8bit registers for application use.
Writing/Reading these registers is done using ‘CLASS 0’ events. Class 0 events are ‘VSCP protocol Functionality’ messages intended for configuring and managing nodes.

Module Description File
Keeping track of which register serves what purpose can be a challenge, especially for the application specific registers. But this is where the module description file or MDF comes in. The MDF file is a machine-readable XML file describing the function of each register of a module, giving the configuration options for that register, etc. This file is used by configuration software (VSCPWorks) to show configuration options specific for the module addressed. The MDF file can be stored on the node itself and fetched from there by VSCPWorks, but more commonly the MDF file will be an XML file hosted on a webserver somewhere. A node then just needs to inform VSCPWorks where (URL) the XML file can be found. This URL is present in the VSCP reserved registers 0xe0-0xff.

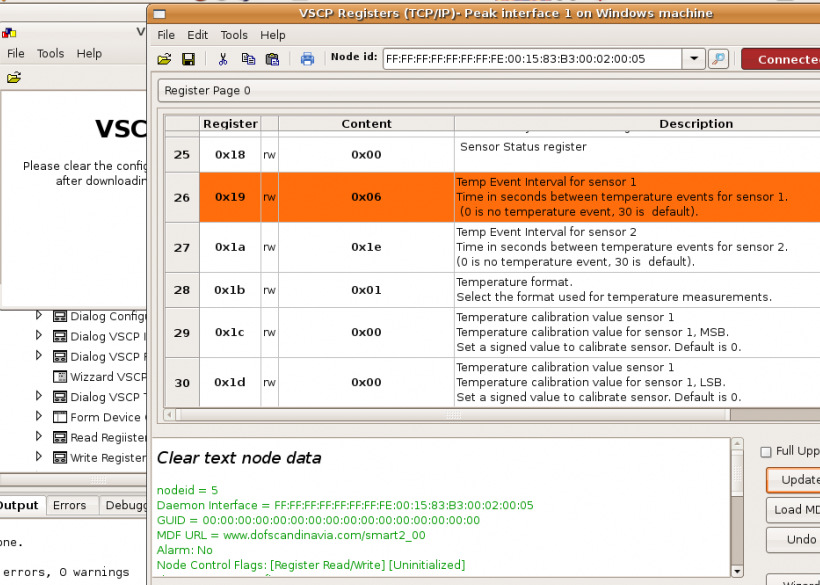
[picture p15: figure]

VSCPWorks
VSCPworks is the PC (Linux & Windows)
based tool to configure & manage the nodes.
VSCPWorks allows reading/setting registers presenting those registers in a human-readable format by parsing the MDF file automatically. VSCPWorks also provides wizards to set the decision matrix.

--- END ---

GUID
MDF URL

0x00

0x7F
0x80

0xFF

Page

Application
register
space
(paged)

VSCP
register
space

Device ID
Nickname ID

Decision matrix

Application
specific registers

Application
specific registers

### Epilogue

Above 4 pages are really a very short primer to VSCP. I’ve limited myself to 4 pages since that was the goal … a good spec should be explainable in 4 pages ;-)

Limiting myself to 4 pages doesn’t allow me to cover every little detail of VSCP but above pages should give the reader the basic concepts behind VSCP and the necessary overview to dive into the Wiki (& don’t get drowned).

The Wiki can be found a www.vscp.org … but beware, it is a big … and a bit chaotic.

VSCP is not finished yet. The project needs additional developers to bring it to the next level. Interested? … then let us know on the mailing list.

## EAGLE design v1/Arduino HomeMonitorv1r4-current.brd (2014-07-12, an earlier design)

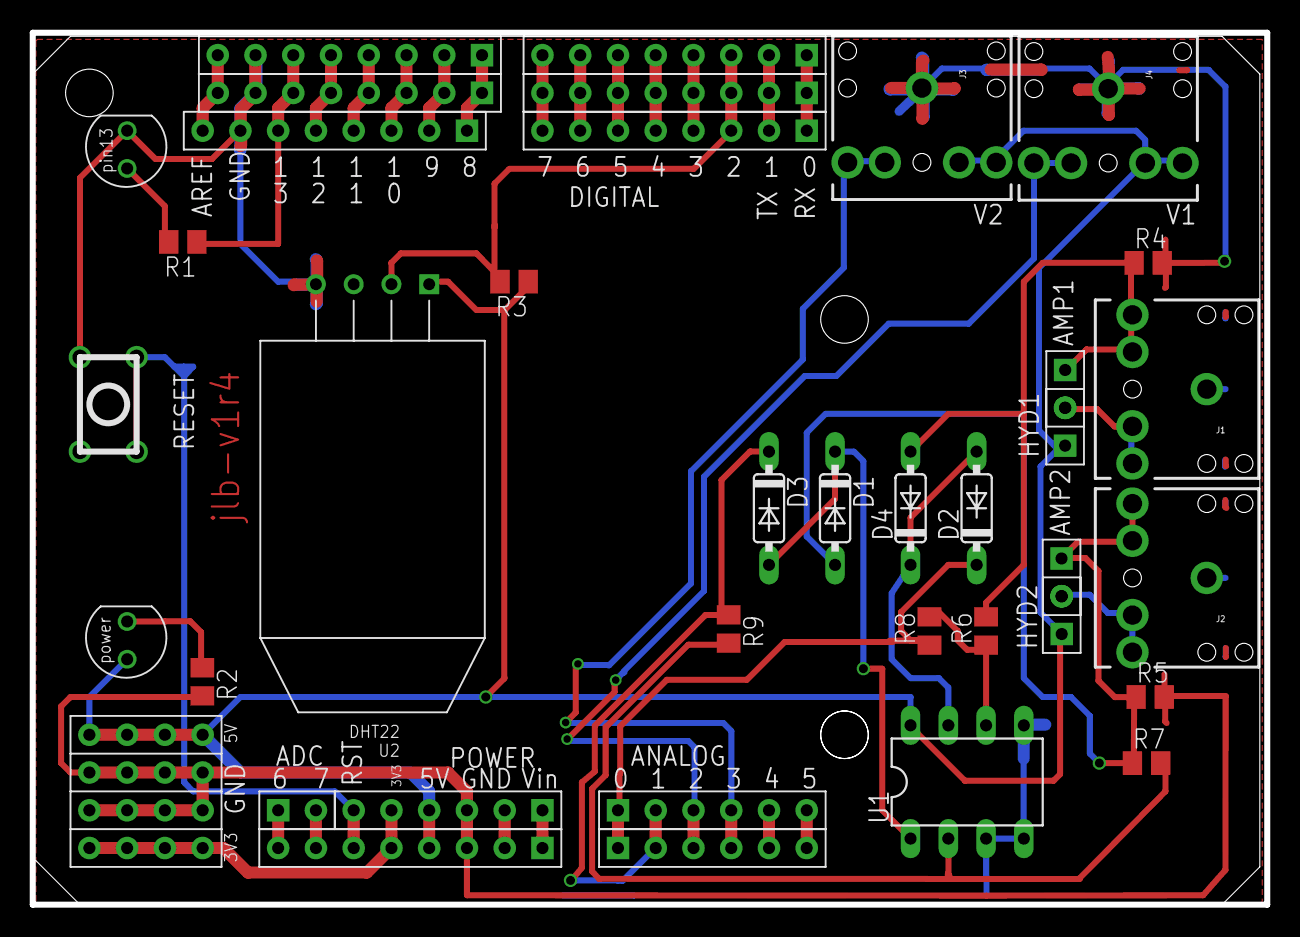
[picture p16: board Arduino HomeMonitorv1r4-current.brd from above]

Board: 2 copper layers, 83.1 x 58.7 mm, 34 parts (0 on the bottom side), 30 nets.

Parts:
ADC6_1, ADC6_2, ADC6_3, ADC6_4, ADC6_7: CK_12; CK_1*2
D1, D2, D3, D4: DO35-7
J1, J2, J3, J4: AUDIO-JACK
PB, PB1, PB2: CK_1X8
PC, PC1: CK_1*6
PD, PD1, PD2, PD3: CK_1X8
POWER: CK_1*6
R1, R2, R3, R4, R5, R6, R7, R8, R9: M0805
U1: DIL08
U2: DHT22; AM2302

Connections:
3V3: PD3.5, POWER.5
5V: PD3.4, POWER.4, U1.8
GND: J1.SLEEVE, J2.SLEEVE, PB.7, PB1.7, PB2.7, PD3.2, PD3.3, POWER.2, POWER.3, U1.3, U1.4
RST: PD3.6, POWER.6
RX: PD.1, PD1.1, PD2.1
S$3: PC.4, PC1.4
S$4: PC.3, PC1.3
S$5: D2.A, D4.C, U1.7
S$15: D1.C, D3.A, U1.1
S$26: PC.1, PC1.1
S$30: PC.2, PC1.2
S$168: PB.6, PB1.6, PB2.6
S$171: PD3.1, POWER.1
S$174: ADC6_7.1, PD3.8
S$177: ADC6_7.2, PD3.7
S$179: PD.4, PD1.4, PD2.4
S$180: PD.3, PD1.3, PD2.3
S$181: PD.5, PD1.5, PD2.5
S$182: PD.6, PD1.6, PD2.6
S$183: PD.7, PD1.7, PD2.7
S$184: PD.8, PD1.8, PD2.8
S$185: PB.1, PB1.1, PB2.1
S$186: PB.2, PB1.2, PB2.2
S$187: PB.3, PB1.3, PB2.3
S$188: PB.4, PB1.4, PB2.4
S$189: PB.5, PB1.5, PB2.5
S$191: PB.8, PB1.8, PB2.8
SCL: PC.6, PC1.6
SDA: PC.5, PC1.5
TX: PD.2, PD1.2, PD2.2

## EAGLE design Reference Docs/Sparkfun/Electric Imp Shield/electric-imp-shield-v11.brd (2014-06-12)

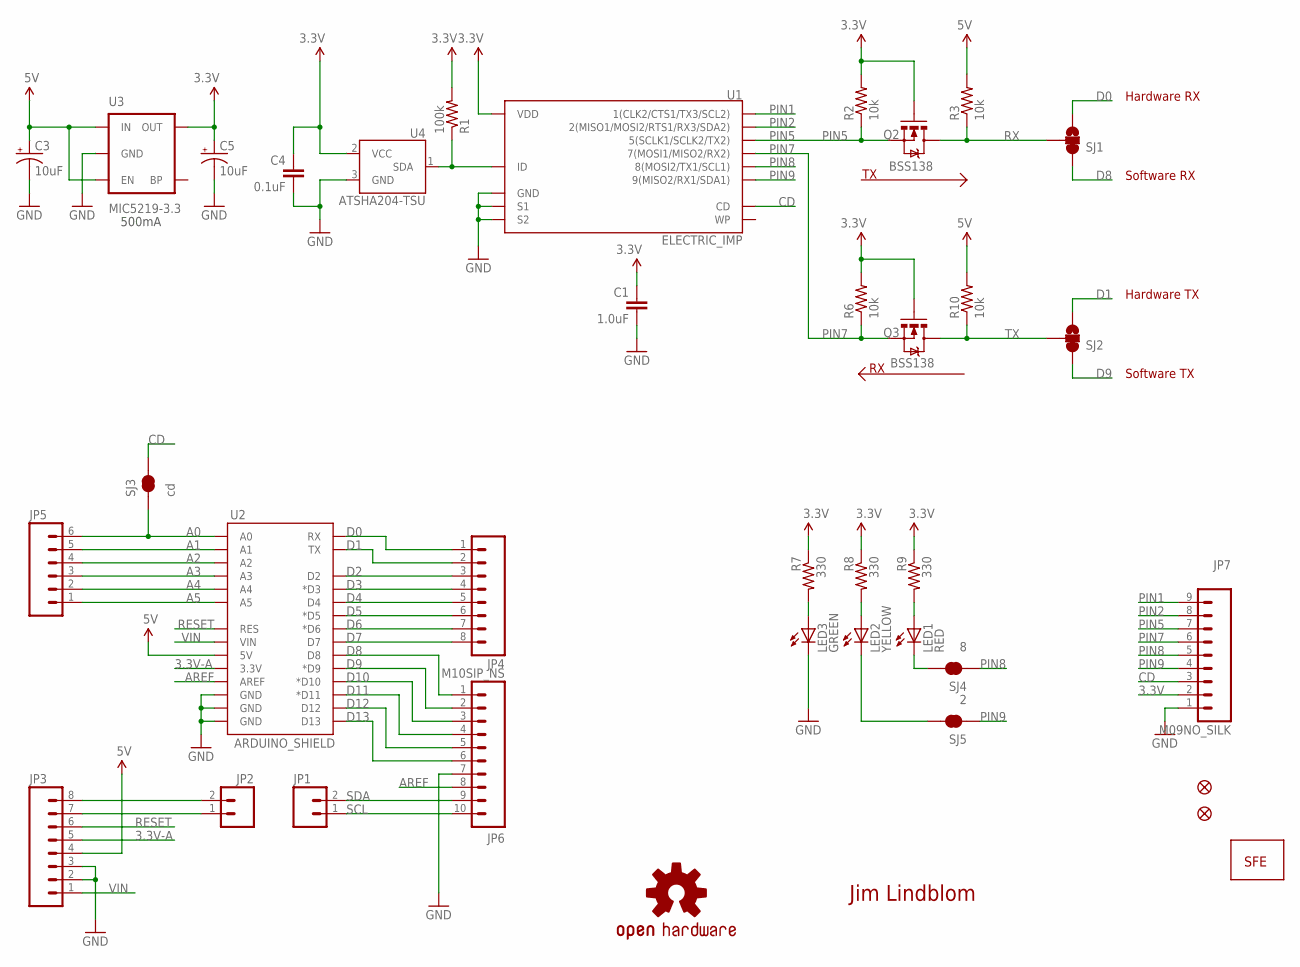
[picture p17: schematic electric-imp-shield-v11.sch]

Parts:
C1: 1.0uF; 0402-CAP
C3, C5: 10uF; EIA3216
C4: 0.1uF; 0402-CAP
JP1, JP2: M021X02_NO_SILK; 1X02_NO_SILK
JP3, JP4: M08SIP_NS; 1X08_NO_SILK
JP5: M06SIP_NS; 1X06_NO_SILK
JP6: M10SIP_NS; 1X10_NO_SILK
JP7: M09NO_SILK; 1X09_NO_SILK
JP8, JP9: FIDUCIALUFIDUCIAL; MICRO-FIDUCIAL
JP10: LOGO-SFENW2; SFE-NEW-WEB
LED1: RED; LED-0603
LED2: YELLOW; LED-0603
LED3: GREEN; LED-0603
Q2, Q3: BSS138; SOT23-3
R1: 100k; 0402-RES
R2, R3, R6, R10: 10k; 0402-RES
R7, R8, R9: 330; 0402-RES
SJ1, SJ2: SOLDERJUMPER_2WAYS; SJ_3
SJ3: cd; SJ_2S-TRACE
SJ4: 8; SJ_2S-TRACE
SJ5: 2; SJ_2S-TRACE
U1: ELECTRIC_IMP; SD_MMC_SOCKET
U2: ARDUINO_SHIELD; DUEMILANOVE_SHIELD_NOHOLES_NOLABELS
U3: MIC5219-3.3; SOT23-5
U4: ATSHA204-TSU; SOT23-3
U$7: OSHW-LOGOS; OSHW-LOGO-S

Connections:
3.3V: C1.1, C4.1, C5.A (+), JP7.2, Q2.1 (G), Q3.1 (G), R1.2, R2.2, R6.2, R7.1, R8.1, R9.1, U1.4 (VDD), U3.5 (OUT), U4.2 (VCC)
3.3V-A: JP3.5, U2.3.3V
5V: C3.A (+), JP3.4, R3.2, R10.2, U2.5V, U3.1 (IN), U3.3 (EN)
A0: JP5.6, SJ3.1, U2.A0
A1: JP5.5, U2.A1
A2: JP5.4, U2.A2
A3: JP5.3, U2.A3
A4: JP5.2, U2.A4
A5: JP5.1, U2.A5
ACTIVITY: LED1.C, SJ4.2
AREF: JP6.8, U2.AREF
CD: JP7.3, SJ3.2, U1.CD
D0: JP4.1, SJ1.3, U2.RX
D1: JP4.2, SJ2.3, U2.TX
D2: JP4.3, U2.D2
D3: JP4.4, U2.D3 (*D3)
D4: JP4.5, U2.D4
D5: JP4.6, U2.D5 (*D5)
D6: JP4.7, U2.D6 (*D6)
D7: JP4.8, U2.D7
D8: JP6.1, SJ1.1, U2.D8
D9: JP6.2, SJ2.1, U2.D9 (*D9)
D10: JP6.3, U2.D10 (*D10)
D11: JP6.4, U2.D11 (*D11)
D12: JP6.5, U2.D12
D13: JP6.6, U2.D13
GND: C1.2, C3.C (-), C4.2, C5.C (-), JP3.2, JP3.3, JP6.7, JP7.1, LED3.C, U1.3 (GND), U1.S1, U1.S2, U2.GND@0 (GND), U2.GND@1 (GND), U2.GND@2 (GND), U3.2 (GND), U4.3 (GND)
LINK: LED2.C, SJ5.2
unnamed: R1.1, U1.6 (ID), U4.1 (SDA)
unnamed: JP2.2, JP3.8
unnamed: JP2.1, JP3.7
unnamed: LED3.A, R7.2
unnamed: LED2.A, R8.2
unnamed: LED1.A, R9.2
PIN1: JP7.9, U1.1 (1(CLK2/CTS1/TX3/SCL2))
PIN2: JP7.8, U1.2 (2(MISO1/MOSI2/RTS1/RX3/SDA2))
PIN5: JP7.7, Q2.2 (S), R2.1, U1.5 (5(SCLK1/SCLK2/TX2))
PIN7: JP7.6, Q3.2 (S), R6.1, U1.7 (7(MOSI1/MISO2/RX2))
PIN8: JP7.5, SJ4.1, U1.8 (8(MOSI2/TX1/SCL1))
PIN9: JP7.4, SJ5.1, U1.9 (9(MISO2/RX1/SDA1))
RESET: JP3.6, U2.RES
RX: Q2.3 (D), R3.1, SJ1.2
SCL: JP1.1, JP6.10
SDA: JP1.2, JP6.9
TX: Q3.3 (D), R10.1, SJ2.2
VIN: JP3.1, U2.VIN

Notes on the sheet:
Hardware RX
Software RX
Hardware TX
Software TX
500mA
Jim Lindblom

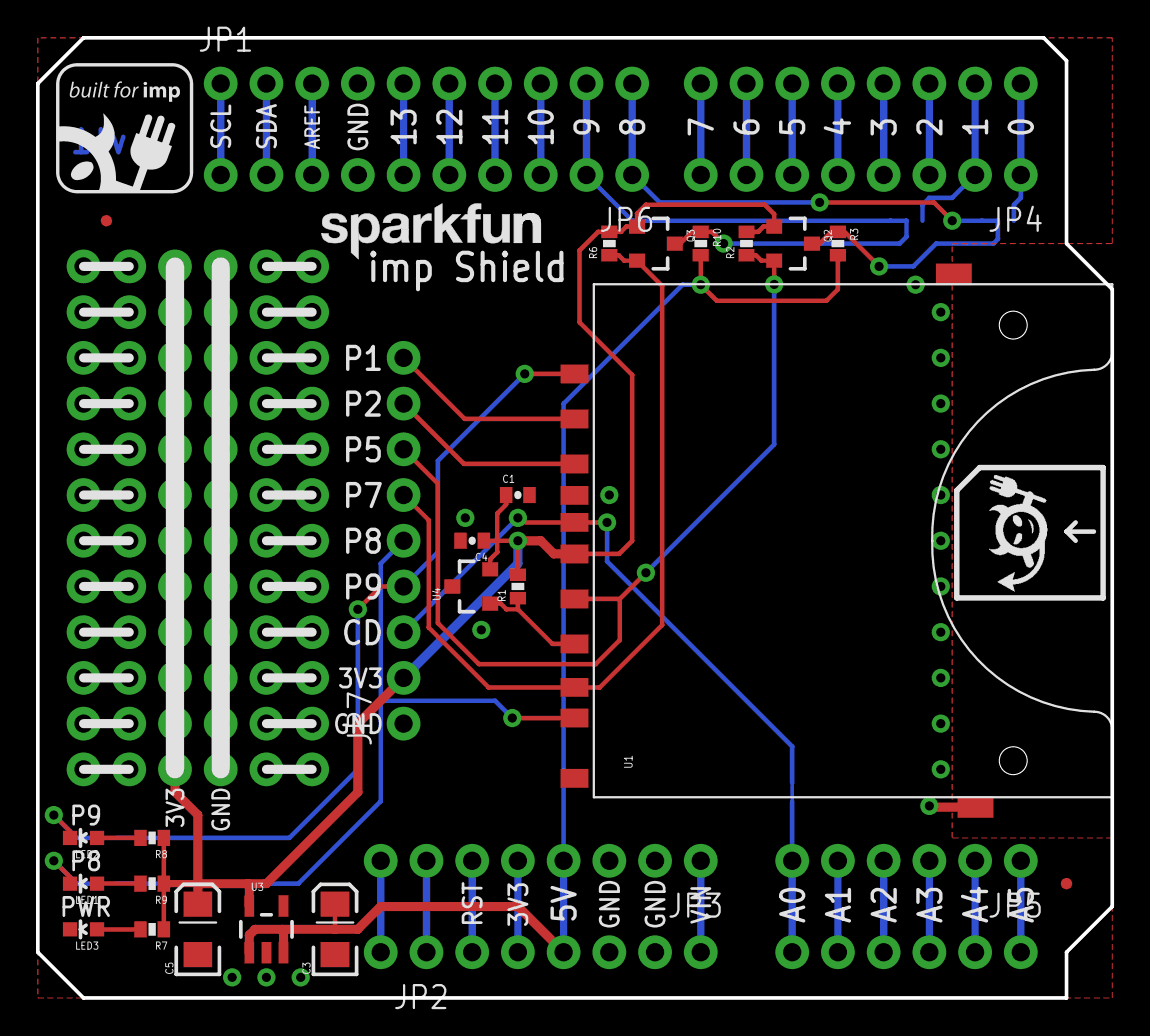
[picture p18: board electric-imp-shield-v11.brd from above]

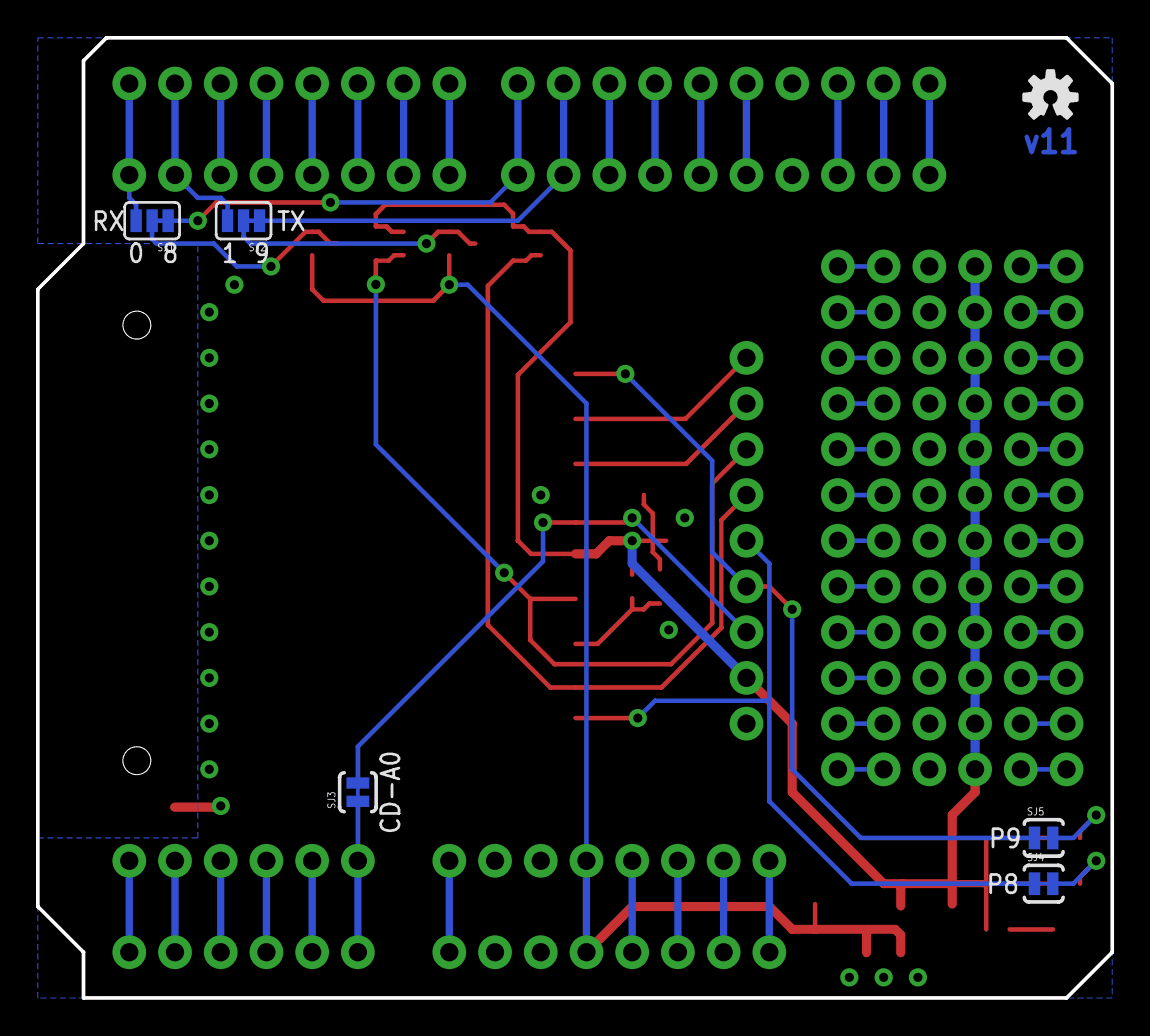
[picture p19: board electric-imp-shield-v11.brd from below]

Board: 2 copper layers, 59.7 x 53.3 mm, 37 parts (6 on the bottom side), 46 nets.

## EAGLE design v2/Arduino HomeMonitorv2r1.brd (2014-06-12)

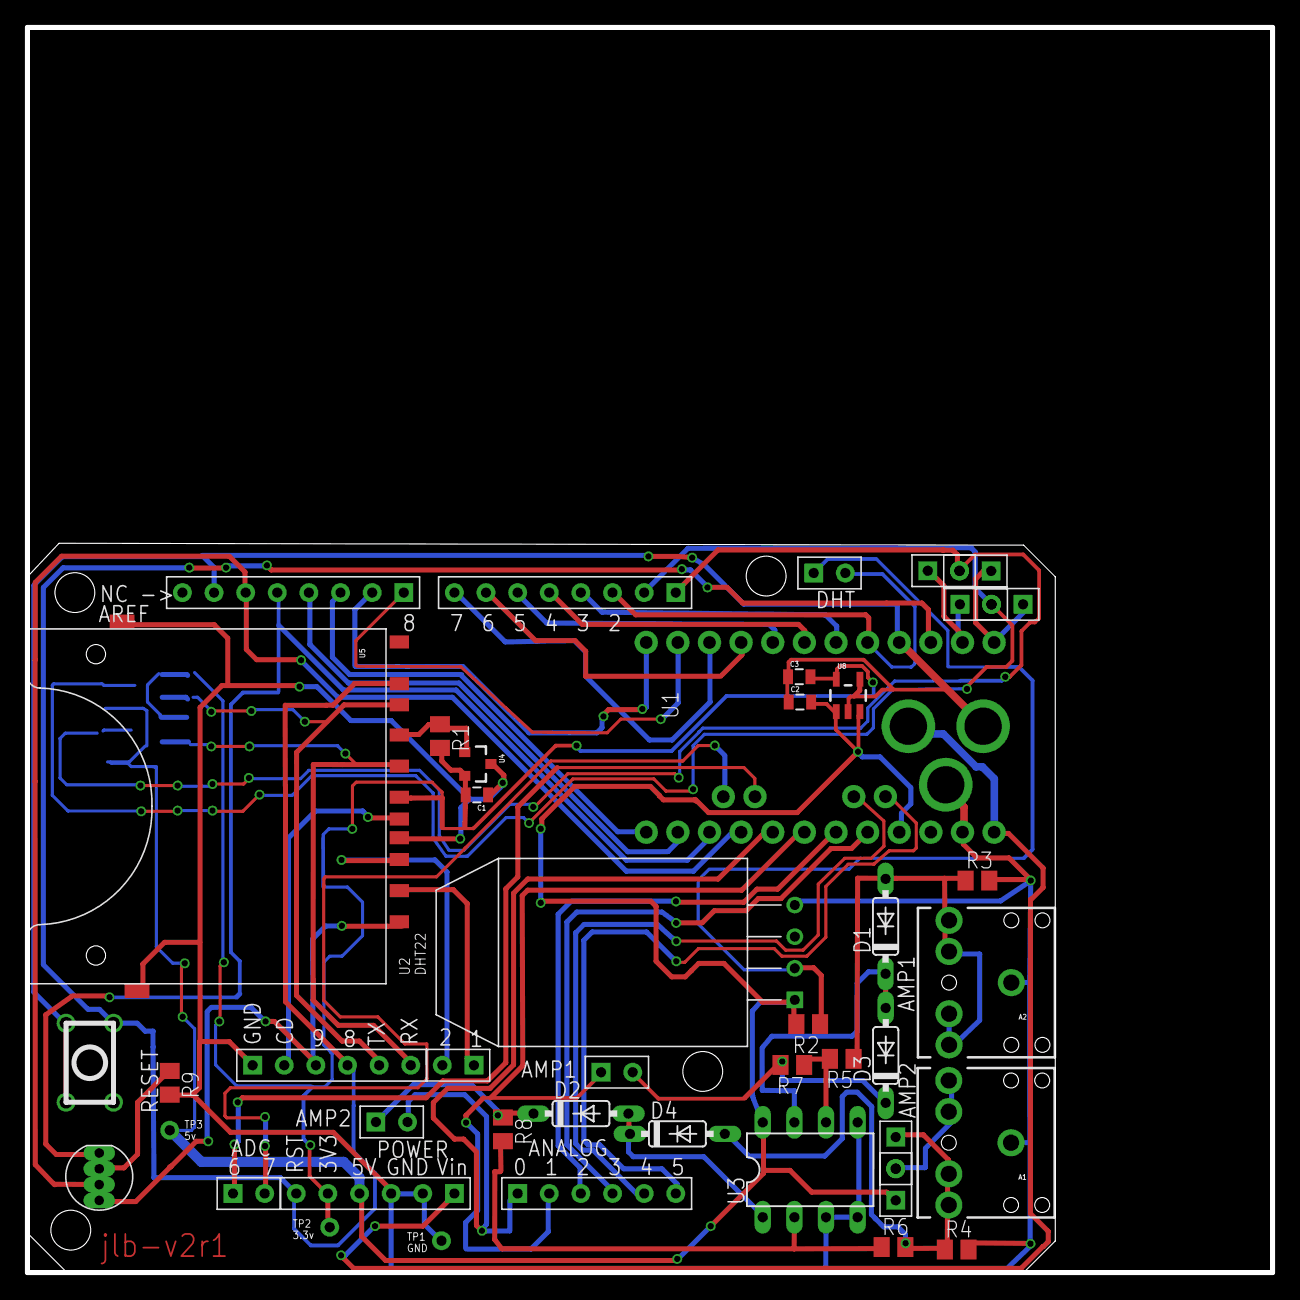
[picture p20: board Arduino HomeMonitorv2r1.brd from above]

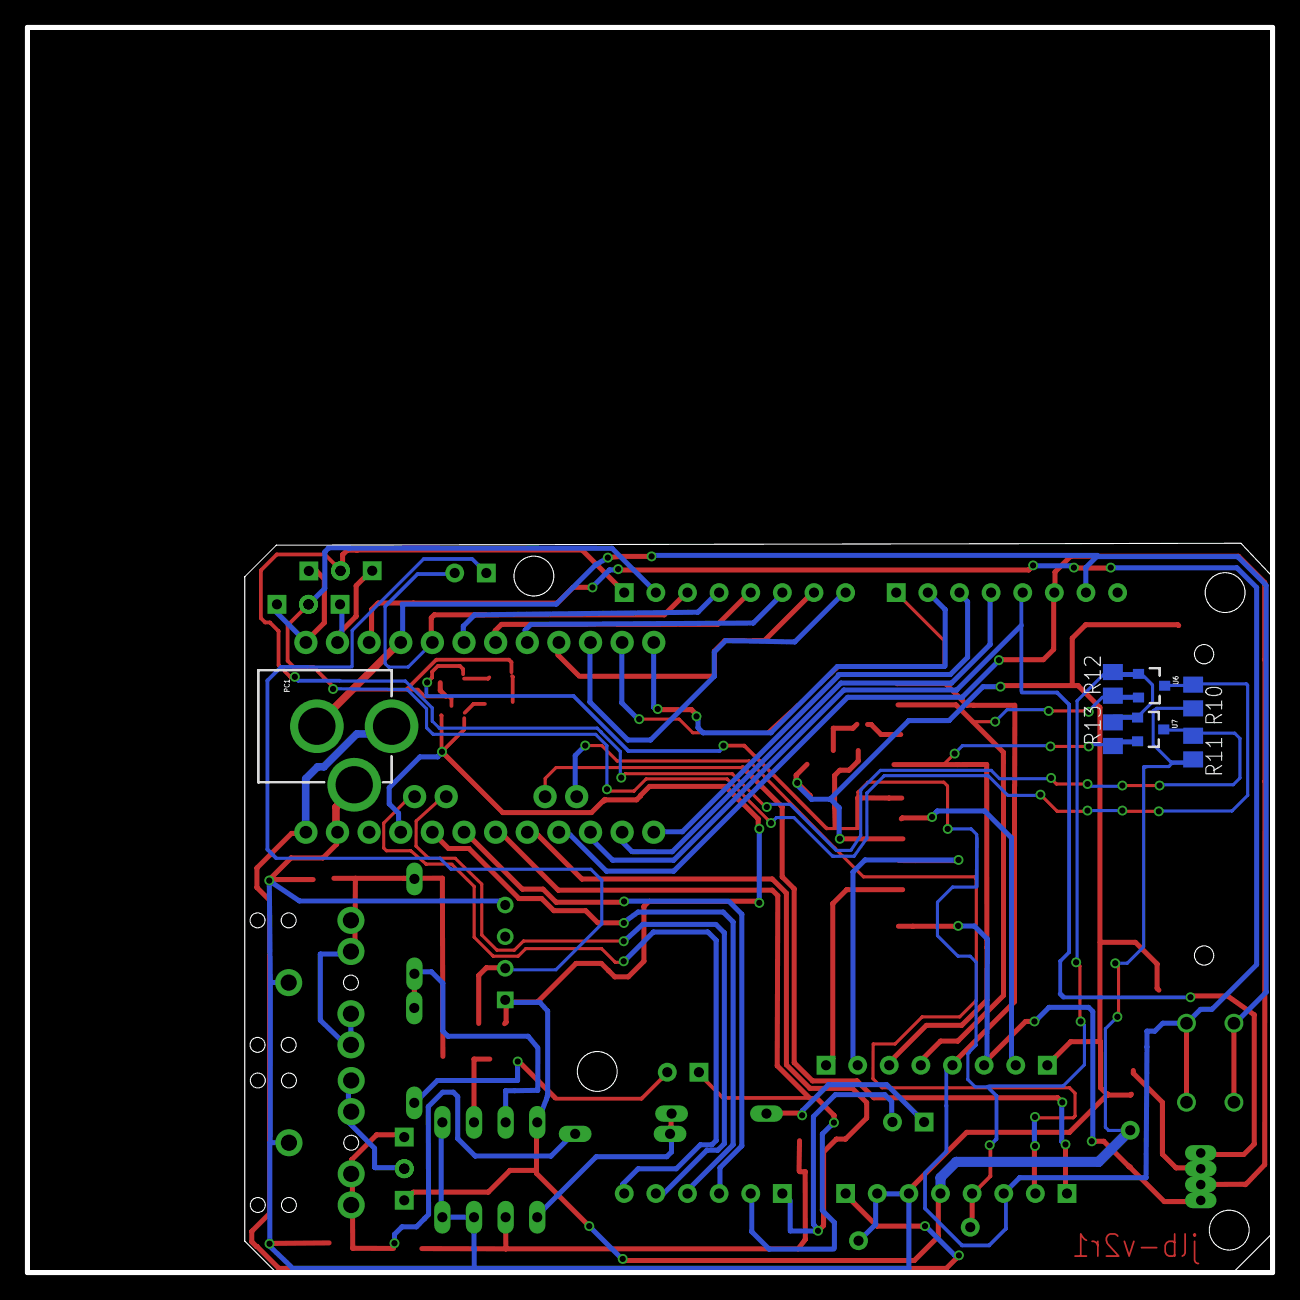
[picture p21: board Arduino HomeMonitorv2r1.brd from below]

Board: 2 copper layers, 100.0 x 100.0 mm, 48 parts (7 on the bottom side), 2 nets.

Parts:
A1, A2: AUDIO-JACK
ADC6_1, ADC6_2, ADC6_3, ADC6_4, ADC6_5, ADC6_6, ADC6_7, ADC6_8, ADC6_9, ADC6_10, ADC6_11: CK_12; CK_1*2
C1: 0.1uF; 0805
C2, C3: 10uF; 0805
D1, D2, D3, D4: DO35-7
E$1: LED-RGB-THRU
PB: CK_1X8
PC: CK_1*6
PC1: POWER_JACK_PTH
PD: CK_1X8
POWER, POWER1: CK_1*6
R1: 100k; M0805
R2, R3, R4, R5, R6, R7, R8, R9, R10, R11, R12, R13: M0805
U1: ARDUINO_PRO_MINI
U2: DHT22; AM2302
U3: DIL08
U4: ATSHA204-TSU; SOT23-3
U5: SD_MMC_SOCKET
U6: BSS138; SOT23-3
U7: SOT23-3
U8: MIC5219-3.3; SOT23-5

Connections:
---: U3.3, U3.4
S$263: A1.SLEEVE, A2.SLEEVE

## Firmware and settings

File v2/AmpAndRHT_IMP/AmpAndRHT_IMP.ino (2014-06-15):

#define DEBUG false
#include <DHT22.h>

// Data wire for RTH03 is plugged into port 7 on the Arduino
// Connect a 4.7K resistor between VCC and the data pin (strong pullup)
#define DHT22_PIN 2

#define LM358N1_PIN 0
#define LM358N2_PIN 1
#define ledPin 13

int maxReadingLM358N1 = 0;
int maxReadingLM358N2 = 0;
int currReadingLM358N1 = 0;
int currReadingLM358N2 = 0;
float main1 = 0.0;
float main2 = 0.0;
float comb = 0.0;
int ledState = LOW;             

int packetSent = false;

// Setup a DHT22 instance
DHT22 myDHT22(DHT22_PIN);


void setup(){
  // Open serial communications and wait for port to open:
  Serial.begin(115200);
  //while (!Serial) {
  // ; // wait for serial port to connect. Needed for Leonardo only
  // }  
  pinMode(ledPin, OUTPUT);    
 }
 
 void loop(){
   //----------------Amperage--------------------------------------------------
   //Reset values for new packet
   if (packetSent){
     packetSent = false;
     maxReadingLM358N1 = 0;
     maxReadingLM358N2 = 0;
   }
   int i;
   for (i=0; i<250; i++) {
     // Get ADC reading for both sensors
     currReadingLM358N1 = analogRead(LM358N1_PIN);
     currReadingLM358N2 = analogRead(LM358N2_PIN);
     
     if (currReadingLM358N1 > maxReadingLM358N1) {
       maxReadingLM358N1 = currReadingLM358N1;
       }
     if (currReadingLM358N2 > maxReadingLM358N2) { 
       maxReadingLM358N2 = currReadingLM358N2;
       }
     
   }
   //                           \/ -- Arduino AREF                 \/--------Burden Resistance
   main1 = (maxReadingLM358N1 * 5 * 3100.0) / (1023.0 * sqrt(2) * 150);
   main2 = (maxReadingLM358N2 * 5 * 3100.0) / (1023.0 * sqrt(2) * 150);
   comb = main1 + main2;
   
  //-----------------------------------------------------------------------------
  //---------------------RHT-----------------------------------------------------
  DHT22_ERROR_t errorCode;
  float temperature = 0;
  float tempF = 0;
  float humidity = 0;
  
  DHT22_ERROR_t errorCode2;
  float temperature2 = 0;
  float tempF2 = 0;
  float humidity2 = 0;
  // The sensor can only be read from every 1-2s, and requires a minimum
  // 2s warm-up after power-on.
  delay(2000);
  errorCode = myDHT22.readData();
  temperature = myDHT22.getTemperatureC();
  humidity = myDHT22.getHumidity();
  tempF = (temperature*1.8)+32;
  
  #if DEBUG
    Serial.println("Temp: ");
    Serial.println(tempF);
    Serial.println("Humidity: ");
    Serial.println(humidity);
    Serial.println();
    Serial.println("Raw Reading");
    Serial.println("Main 1: ");
    Serial.println(maxReadingLM358N1);
    Serial.println("Main 2: ");
    Serial.println(maxReadingLM358N2);
    Serial.println();
    Serial.println("Calculated Amperage");
    Serial.println("Main 1: ");
    Serial.println(main1);
    Serial.println("Main 2: ");
    Serial.println(main2);
    Serial.println("Combined: ");
    Serial.println(comb);
    Serial.println("#################################");
    packetSent = true;
  #endif
  
  Serial.print(tempF);
  Serial.print(":");
  Serial.print(humidity);
  Serial.print(":");
  Serial.print(main1);
  Serial.print(":");
  Serial.print(main2);
  Serial.print(":");
  Serial.print(comb);
  Serial.println();
  
  ledState = HIGH;
  digitalWrite(ledPin, ledState);
  delay(15);
  ledState = LOW;
  digitalWrite(ledPin, ledState);
  
  packetSent = true;
  
  switch(errorCode)
  {
    case DHT_ERROR_NONE:
      temperature = myDHT22.getTemperatureC();
      humidity = myDHT22.getHumidity();
      break;
    case DHT_ERROR_CHECKSUM:
      temperature = 100;
      humidity = 100;
      break;
    case DHT_BUS_HUNG:
      Serial.println("BUS Hung ");
      break;
    case DHT_ERROR_NOT_PRESENT:
      Serial.println("Not Present ");
      break;
    case DHT_ERROR_ACK_TOO_LONG:
      Serial.println("ACK time out ");
      break;
    case DHT_ERROR_SYNC_TIMEOUT:
      Serial.println("Sync Timeout ");
      break;
    case DHT_ERROR_DATA_TIMEOUT:
      Serial.println("Data Timeout ");
      break;
    case DHT_ERROR_TOOQUICK:
      Serial.println("RHT03 Polled to quick ");
      break;
  }
  
  //---------------------------------------------------------------------------
  
 }

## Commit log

2014-04-14 Board drawing
    [Arduino HomeMonitor.brd]
2014-04-15 board edit
    [Arduino HomeMonitor.brd]
2014-06-12 new board
    [Arduino HomeMonitorv1r0.brd, Arduino HomeMonitorv1r3-current.brd]
2014-06-12 upload board
    [Arduino HomeMonitorv2r1.brd]
2014-06-13 change board drawing
    [Arduino HomeMonitorv2r1.brd]
2014-06-13 Change v2 Board
    EI pin1 - arduino reset
    EI pin8 - LED
    EI pin9 - LED
    [Arduino HomeMonitorv2r1.brd]
2014-06-15 Add Electric Imp code and restructure files.
    [Arduino HomeMonitorv1r0.brd, Arduino HomeMonitorv1r3-current.brd, Arduino HomeMonitorv2r1.brd]
2014-06-15 Possible Sensor Boards
    [Arduino VoltageBreakerBoardv1r0.brd, Arduino WaterMeterBoardv1r0.brd]
2014-07-06 Rev 4
    [Arduino HomeMonitorv1r3.brd, Arduino HomeMonitorv1r4-current.brd, Arduino HomeMonitorv1r4-current.sch]
2014-07-12 Rev 4
    Fixed some errors
    [Arduino HomeMonitorv1r4-current.brd]
2014-07-12 Copper Pour
    [Arduino HomeMonitorv2r2.brd]

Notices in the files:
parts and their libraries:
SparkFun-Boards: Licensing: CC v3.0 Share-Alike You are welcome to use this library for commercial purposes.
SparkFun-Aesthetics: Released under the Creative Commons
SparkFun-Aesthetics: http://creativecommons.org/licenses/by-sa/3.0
